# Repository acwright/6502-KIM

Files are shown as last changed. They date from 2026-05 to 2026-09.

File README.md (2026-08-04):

6502-KIM
========

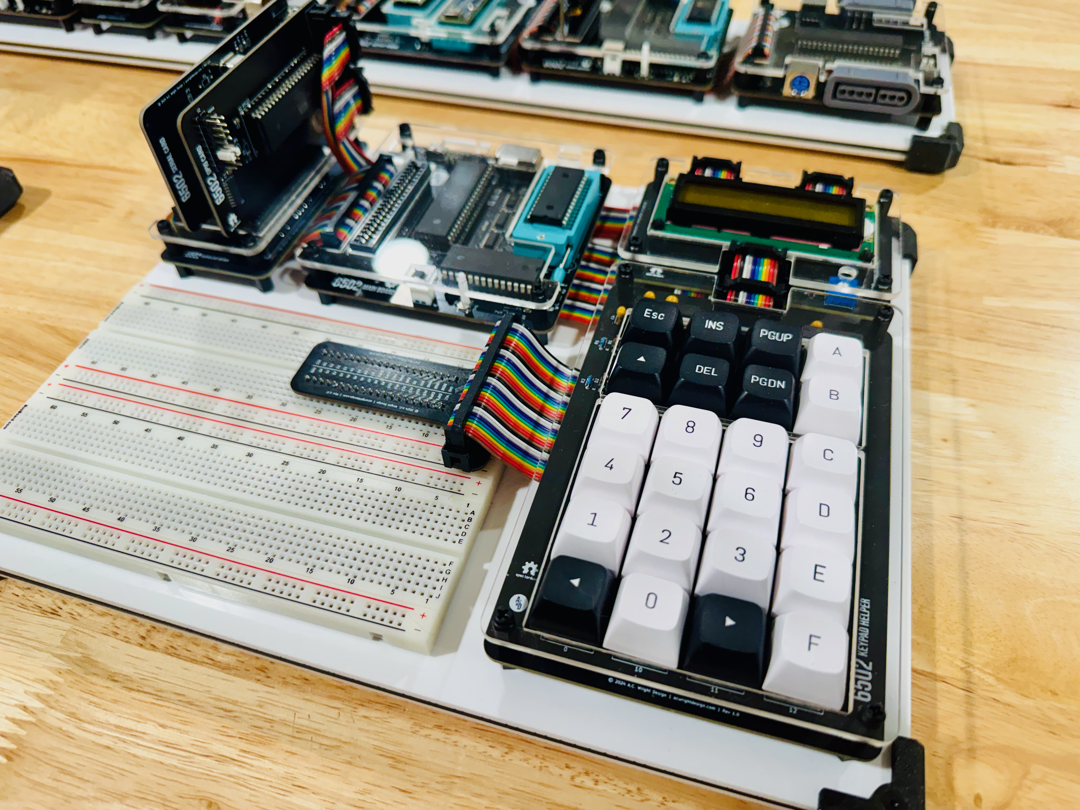
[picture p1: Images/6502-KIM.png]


*(Image shows the alternative Main Board configuration — preferred Backplane/Backplane Pro build pictured separately)*

An **AC6502** retro-style 8-bit computer based on the **65C02** microprocessor.

> 📖 **Guide:** [AC6502 Documentation](https://acwright.github.io/6502-DOCS/) — the user's and programmer's guide for the whole family.
> See [The KIM keypad add-on chapter](https://acwright.github.io/6502-DOCS/addons/kim).

---

## Table of Contents

- [Overview](#overview)
- [Architecture](#architecture)
- [Systems](#systems)
- [Software](#software)
- [Hardware](#hardware)
  - [Backplane / Backplane Pro](#backplane--backplane-pro) *(preferred)*
  - [CPU Card](#cpu-card) *(preferred)*
  - [Memory Card](#memory-card) *(preferred)*
  - [Serial Card](#serial-card)
  - [Backplane Helper](#backplane-helper)
  - [Keypad Card](#keypad-card)
  - [Keypad Helper](#keypad-helper)
  - [Keypad LCD Helper](#keypad-lcd-helper)
  - [Main Board](#main-board) *(alternative)*
- [Firmware](#firmware)
- [CAD](#cad)
- [Production](#production)
- [Schematics](#schematics)
- [Libraries](#libraries)
- [Bill of Materials](#bill-of-materials)
  - [Keypad Card](#keypad-card-1)
  - [Keypad Helper](#keypad-helper-1)
  - [Keypad LCD Helper](#keypad-lcd-helper-1)
- [Purchase](#purchase)
- [License](#license)

## Overview

The AC6502 ecosystem is a family of open-source, 65C02-based computers sharing a common architecture, memory map, and [BIOS](https://github.com/acwright/6502-BIOS). Each computer in the family is purpose-built for a different use case but runs the same software and firmware.

The **KIM** (Keypad Input Monitor) is a complete, self-contained 65C02 computer. The preferred way to build it is using a **[Backplane or Backplane Pro](https://github.com/acwright/6502-COB)**, **[CPU Card](https://github.com/acwright/6502-COB)**, and **[Memory Card](https://github.com/acwright/6502-COB)** from the COB project, along with the **[Serial Card](https://github.com/acwright/6502-COB)** and **[Backplane Helper](https://github.com/acwright/6502-COB)** (also from COB) and the **Keypad Card** — a card that the **Keypad Helper** (keypad matrix) and **Keypad LCD Helper** (16x2 LCD display) attach to. As an alternative, the **[Main Board](https://github.com/acwright/6502-VCS)** from the VCS project can be substituted for the Backplane/CPU/Memory combination.

## Architecture

All AC6502 computers share:

- **CPU**: 65C02 (or accurate emulation)
- **Memory**: 32KB RAM + 32KB ROM, with optional banked RAM expansion
- **Memory Map**: Standardized across the ecosystem — zero page, stack, I/O space ($8000–$9FFF), system ROM, and interrupt vectors at $FFFA–$FFFF
- **Bus**: 16-bit address bus, 8-bit bidirectional data bus, standard 65C02 control signals (RW, PHI2, RESET, IRQ, NMI, RDY, SYNC)
- **BIOS**: A common [BIOS](https://github.com/acwright/6502-BIOS) provides the kernel, monitor, and BASIC interpreter across all systems

## Systems

| Project | Description |
|---|---|
| [6502-ACE](https://github.com/acwright/6502-ACE) | All-in-one Computer Experience — A single board computer |
| [6502-COB](https://github.com/acwright/6502-COB) | Computer On a Backplane — Modular desktop computer with expandable card slots |
| [6502-DEV](https://github.com/acwright/6502-DEV) | Development Environment Vehicle — Emulation-based dev system |
| [6502-KIM](https://github.com/acwright/6502-KIM) | Keypad Input Monitor - KIM-1 inspired minimal computer (YOU ARE HERE) |
| [6502-VCS](https://github.com/acwright/6502-VCS) | Video Computer System — Cartridge-based retro gaming console |

## Software

| Project | Description |
|---|---|
| [6502-BIOS](https://github.com/acwright/6502-BIOS) | The shared BIOS (kernel, monitor, BASIC) for all AC6502 computers |
| [6502-EMULATOR](https://github.com/acwright/6502-EMULATOR) | Emulator for the whole family — desktop app, browser build, and a command line for scripted runs |
| [6502-PRG](https://github.com/acwright/6502-PRG) | Template project for writing assembly language programs |
| [6502-CRT](https://github.com/acwright/6502-CRT) | Template project for writing assembly language cartridges |
| [6502-ASM](https://github.com/acwright/6502-ASM) | Assembly language example programs and demos |
| [6502-BAS](https://github.com/acwright/6502-BAS) | BASIC program listings |
| [6502-WOZMON](https://github.com/acwright/6502-WOZMON) | Wozmon as a standalone ROM |
| [6502-NOP](https://github.com/acwright/6502-NOP) | An all-NOP ROM, for probing a board during bring-up |
| [6502-DOCS](https://github.com/acwright/6502-DOCS) | The documentation site — the guide, the printable reference cards, branding and label artwork |
| [cffs](https://github.com/acwright/cffs) | Builds CompactFlash disk images for the BIOS filesystem |
| [bastok](https://github.com/acwright/bastok) | Tokenizes BASIC listings into `.prg` images, and back |
| [bin2woz](https://github.com/acwright/bin2woz) | Converts a binary into a Wozmon serial upload |

## Hardware

This repository contains KiCad 7.0+ PCB designs for the KIM-specific hardware. The KIM also uses boards, cards, and helpers from the [6502-COB](https://github.com/acwright/6502-COB) project, and optionally from the [6502-VCS](https://github.com/acwright/6502-VCS) project.

### Backplane / Backplane Pro
[`Hardware/Backplane/`](https://github.com/acwright/6502-COB/tree/main/Hardware/Backplane) *(6502-COB — preferred)*

Passive backplane providing 5 card slots with full bus interconnect across all slots. The **Backplane Pro** is an enhanced variant with integrated clock generation, reset circuitry, and power distribution.

### CPU Card
[`Hardware/CPU Card/`](https://github.com/acwright/6502-COB/tree/main/Hardware/CPU%20Card) *(6502-COB — preferred)*

Hosts the 65C02 CPU in a card form factor. Plugs into the Backplane or Backplane Pro.

### Memory Card
[`Hardware/Memory Card/`](https://github.com/acwright/6502-COB/tree/main/Hardware/Memory%20Card) *(6502-COB — preferred)*

Provides 32KB SRAM and 32KB EEPROM with address decoding logic. Plugs into the Backplane or Backplane Pro.

### Serial Card
[`Hardware/Serial Card/`](https://github.com/acwright/6502-COB/tree/main/Hardware/Serial%20Card) *(6502-COB)*

RS-232 serial communication via 65C51 ACIA and MAX232 level shifter. Optional — usually fitted, and required for the KC Monitor's serial monitor, but the KIM runs keypad-only without it.

### Backplane Helper
[`Hardware/Backplane Helper/`](https://github.com/acwright/6502-COB/tree/main/Hardware/Backplane%20Helper) *(6502-COB)*

Adds additional card slots to expand the total backplane configuration.

### Main Board
[`Hardware/Main Board/`](https://github.com/acwright/6502-VCS/tree/main/Hardware/Main%20Board) *(6502-VCS — alternative)*

An all-in-one board containing the 65C02 CPU, 32KB SRAM, 32KB EEPROM, clock, and reset circuitry. Can be used in place of the Backplane + CPU Card + Memory Card combination.

### Keypad Card
`Hardware/Keypad Card/`

The card that makes the KIM a KIM. A cartridge card carrying its own ROM and I/O, which the Keypad Helper and Keypad LCD Helper attach to. Provides:

- **PIA**: 65C21 — Port A carries the keypad code (PA0–PA4) and the LCD control lines (PA5 = RS, PA6 = R/W, PA7 = E); Port B is the LCD data bus. CA1 is the keypad data-available interrupt, CA2 the keypad encoder's output enable.
- **ROM**: AT28C64 8KB EEPROM holding the cartridge firmware — see [Firmware](#firmware)
- **Decoding**: two 74HC138 decoders
- **Ports**: PORT A and PORT B headers for the keypad accessories

Unlike every other card in the family, the Keypad Card **overlays the top of the address space**. Its ROM replaces BASIC, the Monitor, Wozmon and the CPU vectors, while `$A000–$BFFF` stays reachable and is called into by the cartridge:

| Range | Contents |
|---|---|
| `$A000–$B7FF` | BIOS Kernal (unchanged, still callable) |
| `$B800–$BFFF` | CP437 character set (unchanged, still readable) |
| `$C000–$DFFF` | PIA registers (mirrored I/O window) |
| `$E000–$FFF9` | Cartridge ROM (AT28C64, 8KB) |
| `$FFFA–$FFFF` | CPU vectors (NMI, RESET, IRQ) — the cartridge's own |

This takeover is the reason the KIM behaves differently from every other system in the family, and it is why the KIM is not currently emulated by the [emulator](https://github.com/acwright/6502-EMULATOR) or the [DEV board](https://github.com/acwright/6502-DEV).

### Keypad Helper
`Hardware/Keypad Helper/`

The keypad itself, attaching to the Keypad Card — either directly to PORT A, or through the pass-through header on the Keypad LCD Helper. Provides:

- **Input**: 24 Cherry MX key switches wired as a 4×6 matrix
- **Encoder**: MM74C922 16-key encoder, extended to 24 keys with a 74HC00
- **Output**: 5-bit keycode plus a data-available strobe over a 2×6 PORT header

Scanning, debounce and encoding are all done in hardware. The helper carries no microcontroller and runs no firmware of its own.

### Keypad LCD Helper
`Hardware/Keypad LCD Helper/`

Display companion board that sits between the Keypad Card and the Keypad Helper. Provides:

- **Display**: 16×2 HD44780 LCD with a 10kΩ contrast trimmer, driven from PORT A (RS, R/W, E) and PORT B (8-bit data bus)
- **Pass-through**: a KEYPAD header carrying PA0–PA4, CA1 and CA2 straight through to the Keypad Helper

Like the Keypad Helper, this board carries no microcontroller and runs no firmware — the LCD is driven directly by the Keypad Card's PIA.

## Firmware

`Firmware/KC Monitor/`

The **KC Monitor** is a 6502 assembly language cartridge ROM for the KIM system. It burns to the Keypad Card's AT28C64 and turns the card into a KIM-1-style hex monitor: browse and edit memory and execute code from the 24-key keypad and 16×2 LCD, with a concurrent Wozmon-compatible serial monitor over the Serial Card when one is fitted. See [`Firmware/KC Monitor/README.md`](./Firmware/KC%20Monitor/README.md).

It is the only firmware in this repository — the Keypad Helper and Keypad LCD Helper are hardware-only boards and run no code.

## CAD
`CAD/`

3D-printable enclosure bases and laser-cut top panels for the KIM system.

## Production
`Production/`

JLCPCB-ready Gerber files and BOM/CPL for PCB fabrication and assembly.

## Schematics
`Schematics/`

PDF schematics for all KIM hardware.

## Libraries
`Libraries/`

Shared KiCad symbol and footprint libraries used across all AC6502 hardware projects.

## Bill of Materials

### Keypad Card

| Reference | Qty | Value | Description | LCSC | DigiKey | Mouser | Other |
|---|-----|---|---|---|---|---|---|
| C1–C4 | 4 | 100nF | SMD Capacitor 0805 | [C49678](https://www.lcsc.com/search?q=C49678) | | | |
| J2, J3 | 2 | PORT A/B | Box Header 2×6 2.54mm | | [2057-BHR-12-VUA-ND](https://www.digikey.com/en/products/filter?keywords=2057-BHR-12-VUA-ND) | | |
| U1, U2 | 2 | 74HC138 | 3-to-8 Line Decoder | [C5602](https://www.lcsc.com/search?q=C5602) | | | |
| U3 | 1 | 65C21 | Peripheral Interface Adapter | | | [955-W65C21N6TPG-14](https://www.mouser.com/ProductDetail/955-W65C21N6TPG-14) | |
| U4 | 1 | AT28C64 | 8K×8 EEPROM | | [AT28C64B-15PU-ND](https://www.digikey.com/en/products/filter?keywords=AT28C64B-15PU-ND) | [556-AT28C64B15PU](https://www.mouser.com/ProductDetail/556-AT28C64B15PU) | |

### Keypad Helper

| Reference | Qty | Value | Description | DigiKey | Mouser | Other |
|---|-----|---|---|---|---|---|
| C1, C2, C4 | 3 | 100nF | Disc Capacitor | [478-5732-ND](https://www.digikey.com/en/products/filter?keywords=478-5732-ND) | | [AMAZON](https://www.amazon.com/PANMILED-Multilayer-Monolithic-Capacitors-Assortment/dp/B0CYQ1Z4G5) |
| C3 | 1 | 1µF | Disc Capacitor | [478-7667-ND](https://www.digikey.com/en/products/filter?keywords=478-7667-ND) | | [AMAZON](https://www.amazon.com/PANMILED-Multilayer-Monolithic-Capacitors-Assortment/dp/B0CYQ1Z4G5) |
| D1, D2 | 2 | 1N914 | Small Signal Diode | [1N914FS-ND](https://www.digikey.com/en/products/filter?keywords=1N914FS-ND) | | |
| J1 | 1 | PORT | Box Header 2×6 2.54mm | [2057-BHR-12-VUA-ND](https://www.digikey.com/en/products/filter?keywords=2057-BHR-12-VUA-ND) | | [AMAZON](https://www.amazon.com/uxcell-2-54mm-2x6-Pin-Straight-Connector/dp/B07DJYVZV2) |
| R1, R2 | 2 | 100kΩ | Resistor | | | [AMAZON](https://www.amazon.com/ALLECIN-8W-Metal-Film-Resistor/dp/B0C77TM3NR) |
| SW1–SW24 | 24 | 0–23 | Cherry MX Switch 1.00u | [CH196-ND](https://www.digikey.com/en/products/filter?keywords=CH196-ND) | | [AMAZON](https://www.amazon.com/dp/B0FYR5TV3X) |
| U1 | 1 | MM74C922 | 16-Key Encoder | | | [AMAZON](https://www.amazon.com/Todiys-74C922N-MM74C922N-Encoder-MM74C922/dp/B08MCJY9LP) |
| U2 | 1 | 74HC00 | Quad 2-Input NAND Gate | [296-1563-5-ND](https://www.digikey.com/en/products/filter?keywords=296-1563-5-ND) | [595-SN74HC00N](https://www.mouser.com/ProductDetail/595-SN74HC00N) | |

### Keypad LCD Helper

| Reference | Qty | Value | Description | DigiKey | Mouser | Other |
|---|-----|---|---|---|---|---|
| J1, J2, J3 | 3 | PORT A/B/KEYPAD | Box Header 2×6 2.54mm | [2057-BHR-12-VUA-ND](https://www.digikey.com/en/products/filter?keywords=2057-BHR-12-VUA-ND) | | [AMAZON](https://www.amazon.com/uxcell-2-54mm-2x6-Pin-Straight-Connector/dp/B07DJYVZV2) |
| R1 | 1 | R | Resistor | | | |
| U2 | 1 | LCD-16X2 | 16×2 LCD Display | | | [AMAZON](https://www.amazon.com/MECCANIXITY-Display-Backlight-Interface-Adapter/dp/B0DSFXK7QK) |
| VR1 | 1 | 10kΩ | Potentiometer | [3386F-103LF-ND](https://www.digikey.com/en/products/filter?keywords=3386F-103LF-ND) | | |

## Purchase

I have a few PCBs available on Tindie for those interested in building their own AC6502 system without ordering from a fab directly.



## License

Hardware designs are released under the [CERN Open Hardware Licence Version 2 – Permissive](https://ohwr.org/cern_ohl_p_v2.txt).  
Firmware is released under the [MIT License](./Firmware/KC%20Monitor/LICENSE).

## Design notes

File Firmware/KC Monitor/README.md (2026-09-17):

KC Monitor
==========

A KIM-1-style keypad/LCD memory monitor for the **Keypad Card (KC)** of the
[AC6502 KIM](https://github.com/acwright/6502-KIM).

KC Monitor is a 6502 cartridge ROM that turns the Keypad Card into a standalone
hex monitor. You can inspect and edit memory, navigate the address space, and
execute code directly from the 24-key keypad and 16×2 LCD. A concurrent,
Wozmon-compatible serial monitor runs at the same time
over the Serial Card, so memory can also be examined, deposited, and executed
from a terminal while the keypad UI stays live. Both consoles run a program the
same way — as a subroutine — so an `RTS` comes back to the monitor whichever one
you launched from.

## Features

- **KIM-1-style keypad monitor** — navigate addresses, edit bytes one nibble at
  a time, and run code from the keypad.
- **16×2 HD44780 LCD display** — shows the current address and the byte stored
  there, plus mode/help on the second line.
- **Execute & return** — launch a program with `UP` from the pad or `XXXX R`
  from the terminal; either runs it as a subroutine, and an `RTS` returns to the
  monitor (and, from the terminal, to a fresh prompt).
- **ESC = break-to-monitor** — press `ESC` to abort a running program from
  anywhere (keypad- or serial-launched) and return to the live monitor.
- **Concurrent Wozmon serial monitor** — the Apple-1 Wozmon command set over the
  Serial Card, running alongside the keypad UI on shared memory.
- **bin2woz compatible** — stream the output of
  [bin2woz](https://github.com/acwright/bin2woz) into the serial port to "upload"
  a binary, then run it with `XXXX R`.

## Hardware

KC Monitor targets the Keypad Card, a cartridge that overlays the `$C000–$FFFF`
address space. It drives:

- A **16×2 HD44780 LCD** and a **24-key keypad** through a **65C21 PIA**.
- The **Serial Card** (R65C51 ACIA) for the concurrent serial monitor. The
  Serial Card is optional: the ACIA is only touched when the BIOS boot probe
  set `HW_SC` in `HW_PRESENT`, so a machine assembled without it comes up as a
  keypad-only monitor rather than reading a floating bus at `$9000`.

| Range | Contents |
|---|---|
| `$C000–$DFFF` | PIA registers (mirrored I/O window) |
| `$E000–$FFF9` | Cartridge ROM (AT28C64, 8 KB) |
| `$FFFA–$FFFF` | CPU vectors (NMI, RESET, IRQ) |

The PIA is mapped with A0=RS0, A1=RS1: `$C000` PORTA/DDRA, `$C001` CRA,
`$C002` PORTB/DDRB, `$C003` CRB. Port A carries the keypad code (PA0–PA4) and the
LCD control lines (PA5=RS, PA6=R/W, PA7=E); Port B is the LCD data bus. Keypad
input is interrupt driven via the 74C922 encoder's data-available signal on CA1.

### Startup

Both consoles show the same splash and both hold at the same gate:

```
KIM MONITOR v1.0
--ESC TO START--
```

`ESC` — and only `ESC` — starts the monitor, and one `ESC` starts both. Press
the keypad `ESC` key or send `$1B` from the terminal; either is caught in the
interrupt handler, so the two behave identically. Nothing else is accepted, and
nothing typed or pressed at the splash is echoed, acted on, or held over: the
gate discards the keypad mailbox and the serial receive ring on the way through.

Once the gate opens, the LCD paints the address/byte display and *then* the
serial `> ` prompt appears. The prompt is the signal that the parser is running
— it is never shown ahead of one.

### Keypad Layout

The 24 keys map to monitor functions:

| Key | Function |
|-----|---|
| `0`–`F` | Enter a hex nibble (address or data) |
| `LEFT` / `RIGHT` | Move the current address ∓1 |
| `PGUP` / `PGDN` | Move the current address ∓`$0100` |
| `INS` | Toggle insert (data-edit) mode |
| `DEL` | Write `$00` at the current address |
| `UP` | Execute code at the current address (returns on `RTS`) |
| `ESC` | Abort a running program back to the monitor |

In navigation mode, hex keys shift the current address one nibble at a time
(KIM-1 style). In `INS` mode, hex keys edit the byte at the current address.

### Serial Monitor

The serial monitor speaks the Apple-1 Wozmon command language at **19200 baud,
8-N-1**.

| Input | Action |
|---|---|
| `XXXX` | Examine the byte at address `XXXX` |
| `XXXX.YYYY` | Examine the range `XXXX` through `YYYY` |
| `XXXX: BB BB …` | Deposit bytes starting at `XXXX` |
| `XXXX R` | Run the program at `XXXX` (returns on `RTS`) |

Because the serial and keypad monitors share the same memory, a serial deposit is
visible on the LCD at the next refresh, and vice versa.

#### Two departures from original Wozmon

The syntax is Wozmon's, byte for byte; two behaviours are not.

- **The prompt is `> `**, not `\`.
- **`R` is a `JSR`, not Wozmon's `JMP (XAML)`.** The pad's `UP` key has always
  run the program under the cursor as a subroutine, so a program ending in `RTS`
  lands back in a live monitor. Serial `R` now does the same, and prints a fresh
  prompt on return. Under the original jump semantics an `RTS` left the terminal
  with no prompt and a line buffer still holding the `XXXX R` that launched the
  program, so the next line typed was appended to it and re-ran the program.
  A program that never returns is unaffected, and `ESC` still breaks out of one.

#### Pasting, and RTS/CTS flow control

A pasted program arrives faster than the monitor can swallow it, so the monitor
signals the far end with **RTS**, the same way the BIOS Kernal does: RTS goes up
at `$C0` unread bytes in the 256-byte receive ring and comes down again below
`$80`. **Set your terminal to RTS/CTS hardware flow control** and a paste of any
length arrives whole at 19200 baud; without it the monitor still never loses more
than the odd character, because a full ring now drops the incoming byte rather
than lapping its own reader.

Two consequences worth knowing, both of them the R6551's doing — TIC `00` raises
RTS *and turns the transmitter off*:

- **The monitor owns `$9002`.** Depositing a command-register value there holds
  only until the next character goes out, which puts RTS back where the ring
  says it belongs. There is no way to leave the board mute from the console.
- **The monitor goes quiet while the ring is full.** Above the high-water mark it
  drops what it was going to say rather than lowering RTS to say it, because
  every one of those windows would let the far end push more in and the ring
  would never recover. So a long paste is echoed only in part. The deposits all
  land; read them back when the paste is done.

The panel is repainted once at the end of a batch rather than once per line: a
full `RefreshDisplay` is about 22 ms of LCD time, which is more than a line of
paste takes to arrive at 19200 baud.

## Building

### Prerequisites

#### cc65 toolchain

KC Monitor is assembled with [cc65](https://github.com/cc65/cc65) (the `cl65`
driver). On macOS:

```bash
brew install cc65
```

#### Optional: minipro (for EEPROM burning)

```bash
brew install minipro
```

### Build Commands

| Command | Description |
|---|---|
| `make` | Assemble the cartridge ROM (`KC Monitor.bin`) |
| `make view` | Display a hexdump of the built ROM |
| `make eeprom` | Burn the ROM to an AT28C64 EEPROM via a TL866 programmer |
| `make clean` | Remove build artifacts |

### Build Output

```bash
make
```

Produces:

- `KC Monitor.bin` — 8 KB ROM image (`$E000–$FFFF`), ready to burn to an AT28C64.
- `KC Monitor.lst` — assembly listing file for debugging.

### Programming the EEPROM

```bash
make eeprom
```

Burns `KC Monitor.bin` to an AT28C64 EEPROM using a TL866-compatible programmer
and minipro.

## Project Structure

| File | Purpose |
|---|---|
| `KC Monitor.asm` | Firmware source — LCD driver, keypad input, monitor state machine, serial monitor, vectors |
| `kim.inc` | Machine include — the KIM as it is *with the cartridge fitted* |
| `kim.cfg` | Linker configuration — 8 KB ROM at `$E000` plus CPU vectors |
| `Makefile` | Build system |

### `kim.inc` vs the family-wide `6502.inc`

The BIOS repository ships a `6502.inc` describing the AC6502 family, and it is
the wrong file to build a KIM against. It documents a fully populated ACE with
the whole 32 KB BIOS ROM intact — banked RAM, RTC, CompactFlash, GPIO, SID,
video, BASIC, the machine code monitor and Wozmon. On a KIM none of those cards
are fitted and the top of the ROM is overlaid by this cartridge, so following
that file leads you to call routines that quietly do nothing, to enter a monitor
that is no longer there, and to reuse "spare" RAM that this firmware is
actively using.

`kim.inc` is the KIM's own machine description and is the file to include. It
states what the overlay removes, tags every Kernal entry point with what it
actually does on a KIM (`[WORKS]`, `[SERIAL]`, `[INERT]`, `[FAILS]`, `[BROKEN]`),
defines only hardware the KIM really has — the Keypad Card PIA and the Serial
Card ACIA — and marks the RAM this monitor owns:

| Region | Reserved for |
|---|---|
| `$40–$51` | Monitor and Wozmon parser state (zero page) |
| `$0200–$027F` | Wozmon line buffer — **live**, despite `6502.inc` calling this page the Kernal's input ring |
| `$0400–$04FF` | Serial RX ring, filled by the cartridge's IRQ handler |

Two consequences catch programs written against the family include: `Chrin` and
the ring routines around it always come back empty (the cartridge owns
`IRQ_PTR`, so the Kernal ring is never fed), and `Chrout` reaches the blocking
`SerialChrout`, which hangs forever if no terminal is asserting `/CTS`.

## License

See [LICENSE](LICENSE).

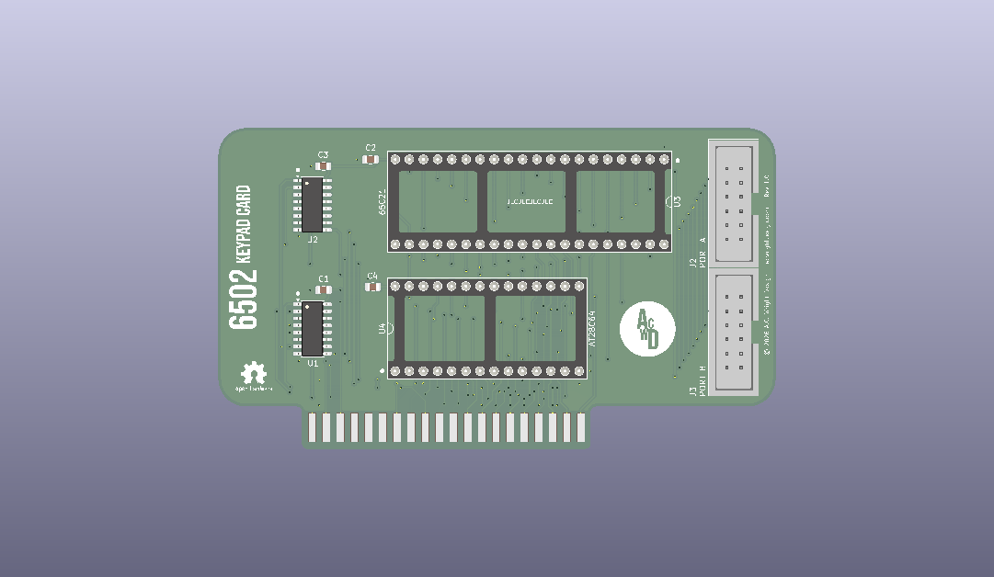
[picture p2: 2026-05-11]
CAD/Images/Keypad Card/Rev 1.0/Front.png

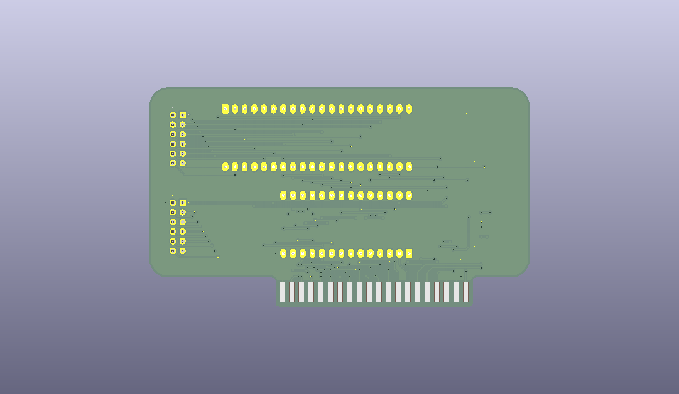
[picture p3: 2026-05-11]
CAD/Images/Keypad Card/Rev 1.0/Back.png

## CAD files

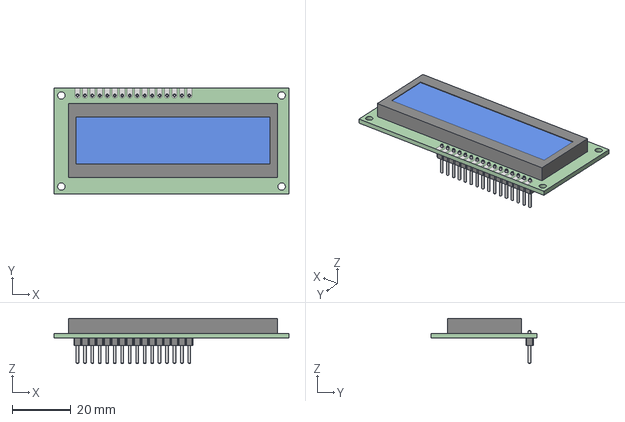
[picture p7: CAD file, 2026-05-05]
Models/LCD 16x2 HD44780 assembly.stp
80.0 x 36.0 x 15.3 mm
lcd 16_2 HD44780
dupont_pin_16

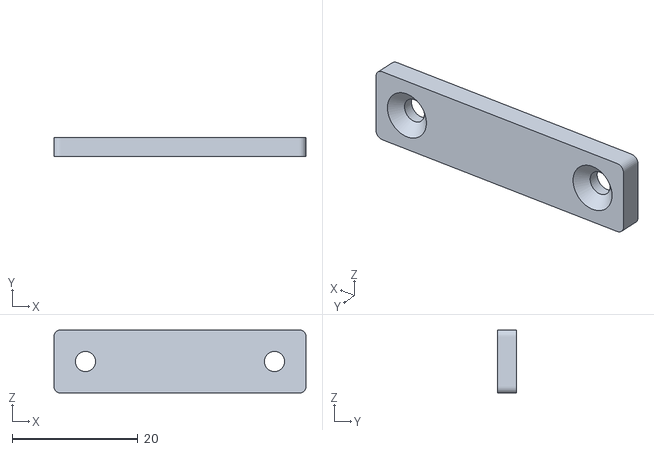
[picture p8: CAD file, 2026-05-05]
CAD/Bases/Hanger Retainer.stl
40.0 x 3.00 x 10.0

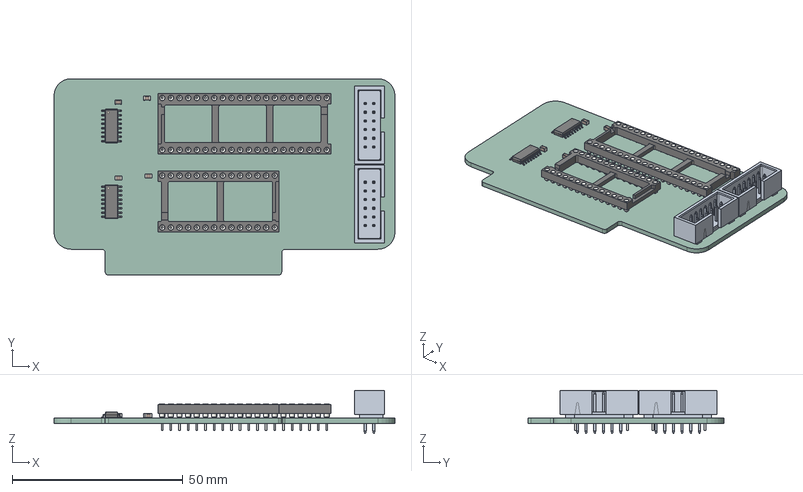
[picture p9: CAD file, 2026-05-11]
CAD/Models/Keypad Card/Rev 1.0/Keypad Card.step
100.0 x 57.6 x 12.7 mm
DIP-28_W15.24mm_Socket
DIP-40_W15.24mm_Socket
C_0805_2012Metric x 4
SOIC-16_3.9x9.9mm_P1.27mm x 2
Keypad Card_PCB

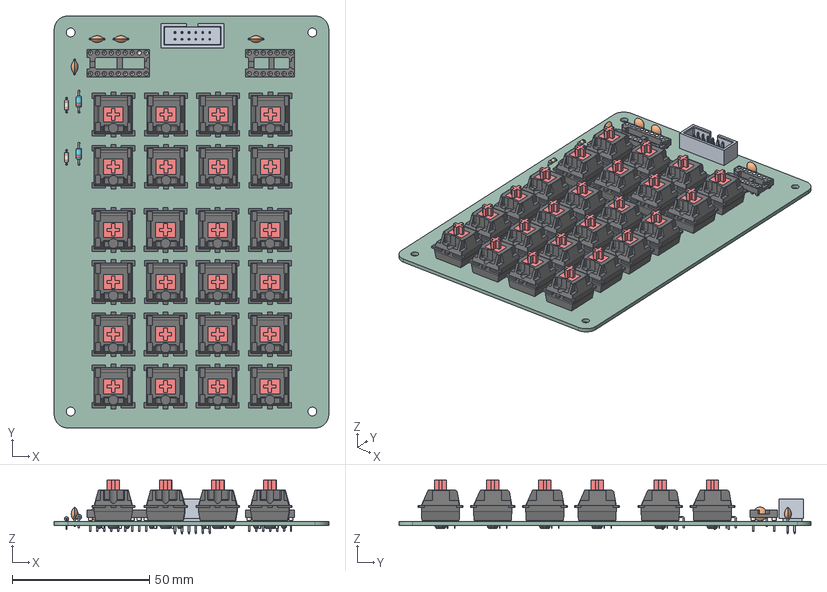
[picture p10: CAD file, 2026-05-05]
CAD/Models/Keypad Helper/Rev 1.0/Keypad Helper.step
100.0 x 150.0 x 19.6 mm
DIP-14_W7.62mm_Socket
D_DO-35_SOD27_P7.62mm_Horizontal x 2
R_Axial_DIN0204_L3.6mm_D1.6mm_P5.08mm_Horizontal x 2
C_Disc_D5.0mm_W2.5mm_P5.00mm x 4
DIP-18_W7.62mm_Socket
Keypad Helper_PCB

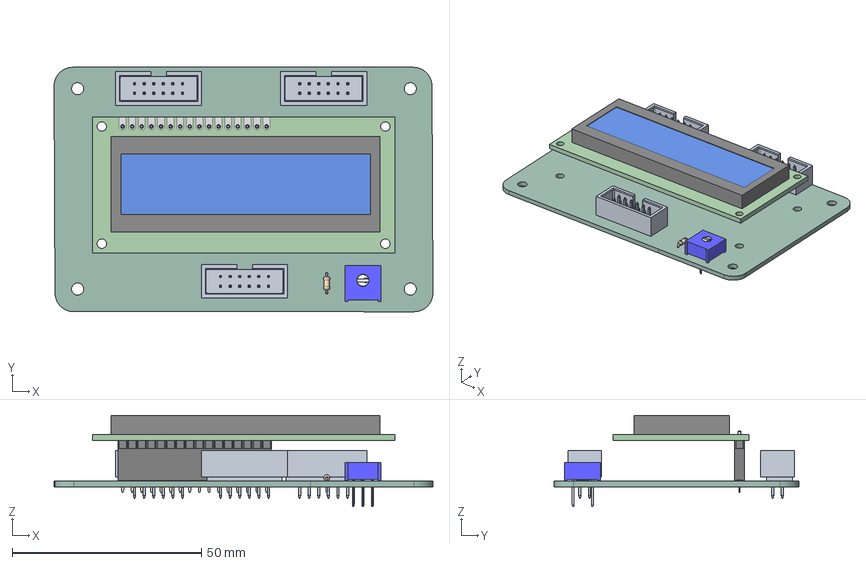
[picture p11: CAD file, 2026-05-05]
CAD/Models/Keypad LCD Helper/Rev 1.0/Keypad LCD Helper.step
100.3 x 64.7 x 24.2 mm
lcd 16_2 HD44780
dupont_pin_16
PinSocket_1x16_P2.54mm_Vertical
R_Axial_DIN0204_L3.6mm_D1.6mm_P5.08mm_Horizontal
3386F-1-103LF
Keypad LCD Helper_PCB

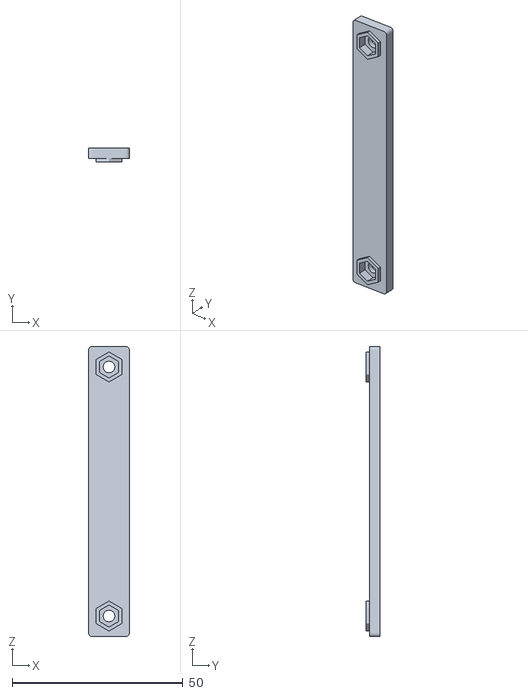
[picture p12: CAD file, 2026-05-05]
CAD/Bases/Cable Bridge Retainer.stl
12.0 x 4.00 x 85.0

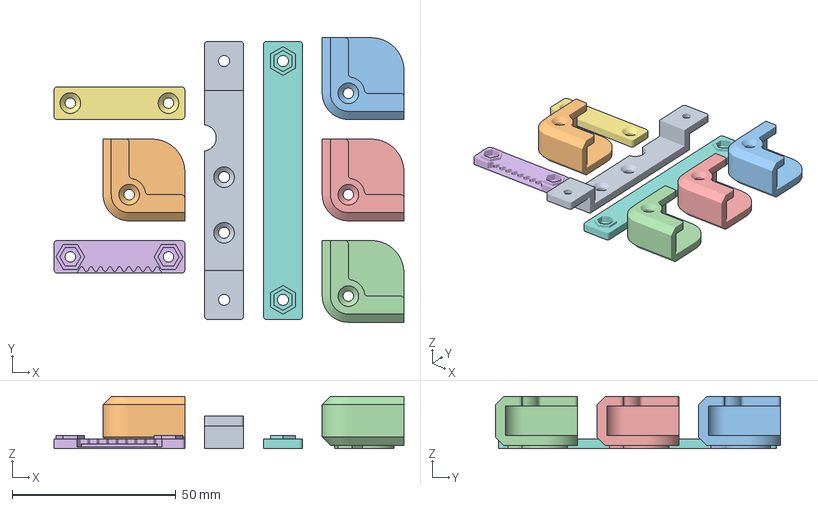
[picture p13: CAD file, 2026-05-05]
CAD/Bases/The KIM.3mf
107.0 x 87.0 x 16.0 mm
Cable Bridge.stl
Corner.stl
Hanger.stl
Hanger Retainer.stl
Cable Bridge Retainer.stl

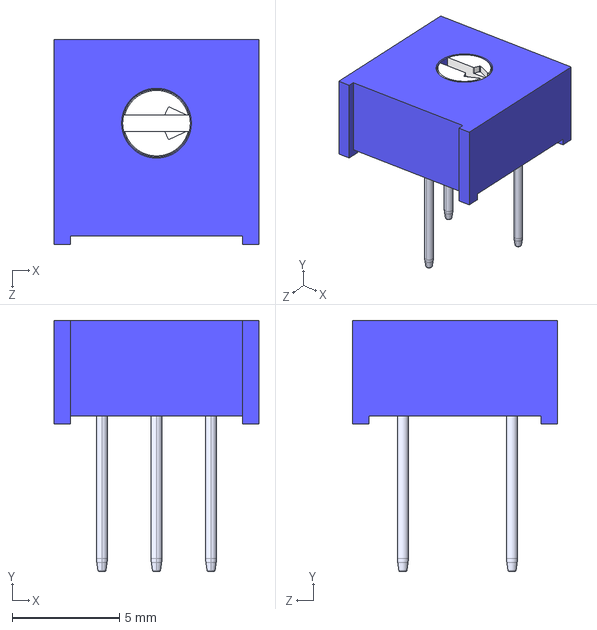
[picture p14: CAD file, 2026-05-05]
Models/3386F-1-103LF.step
9.53 x 11.7 x 9.53 mm

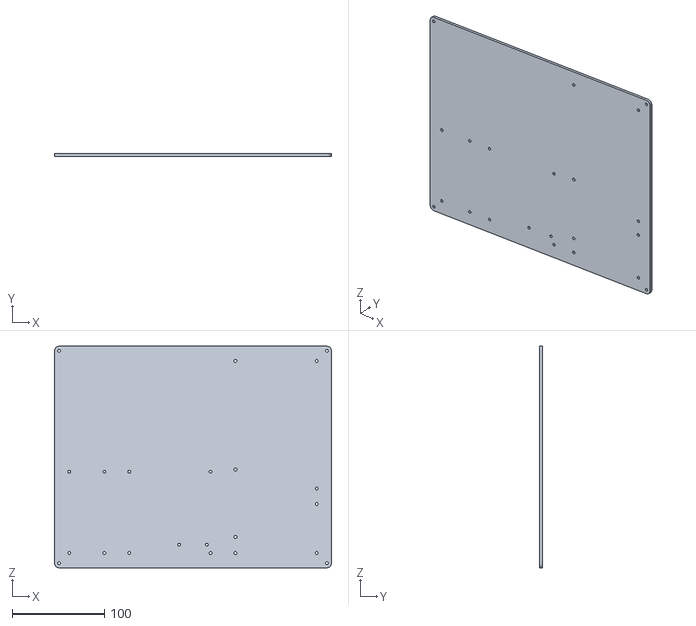
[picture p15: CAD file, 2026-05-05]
CAD/Bases/Plate.stl
300.0 x 3.00 x 240.0

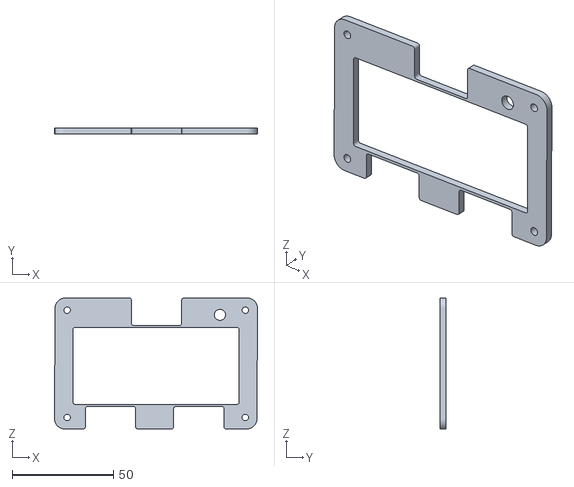
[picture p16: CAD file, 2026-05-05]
CAD/Bases/Keypad LCD Helper Top.stl
100.3 x 3.00 x 64.7

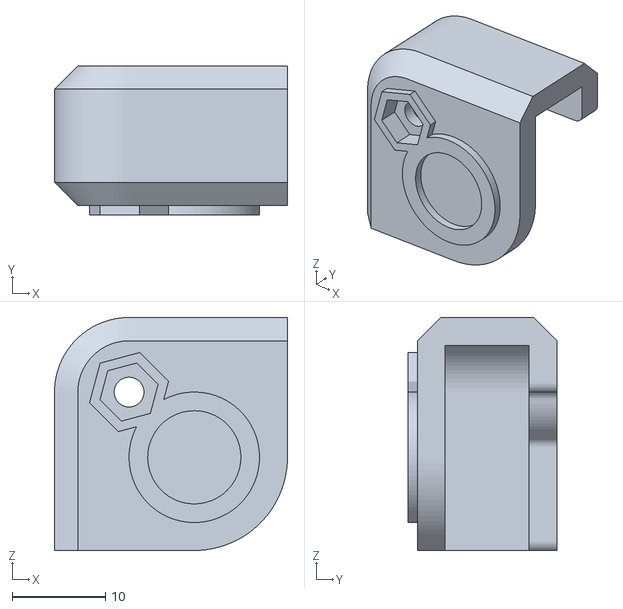
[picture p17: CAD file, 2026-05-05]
CAD/Bases/Corner.stl
25.0 x 16.0 x 25.0

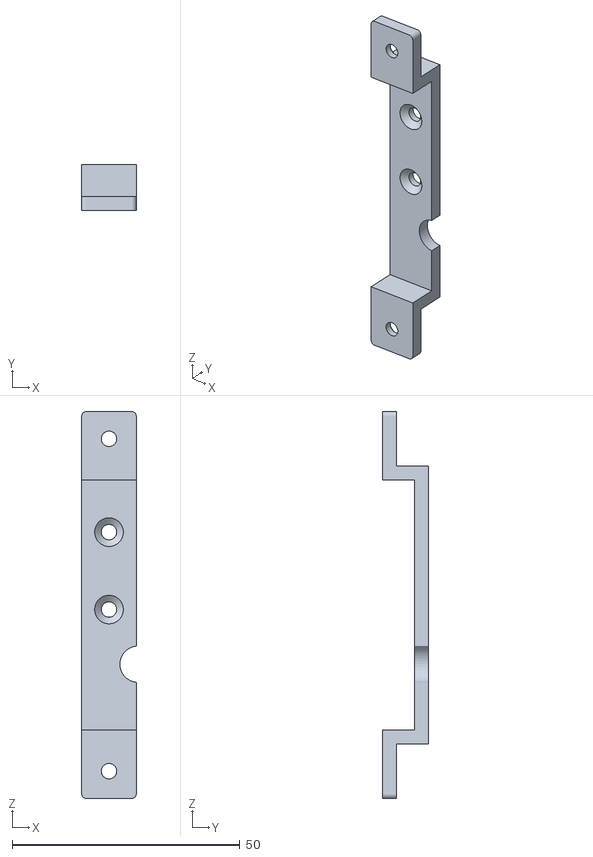
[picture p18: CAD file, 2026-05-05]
CAD/Bases/Cable Bridge.stl
12.0 x 10.0 x 85.0

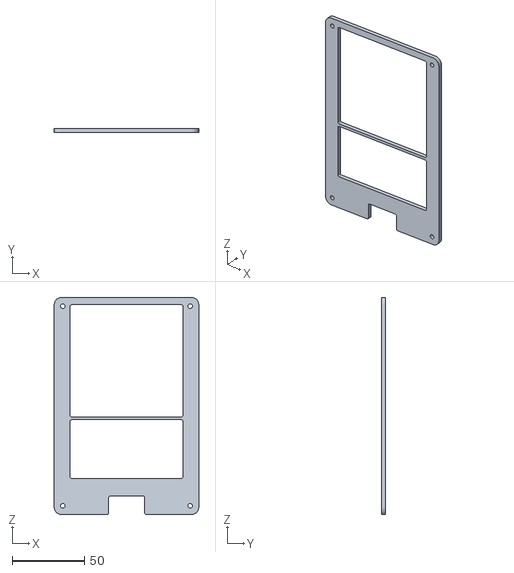
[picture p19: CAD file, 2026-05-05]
CAD/Bases/Keypad Helper Top.stl
100.0 x 3.00 x 150.0

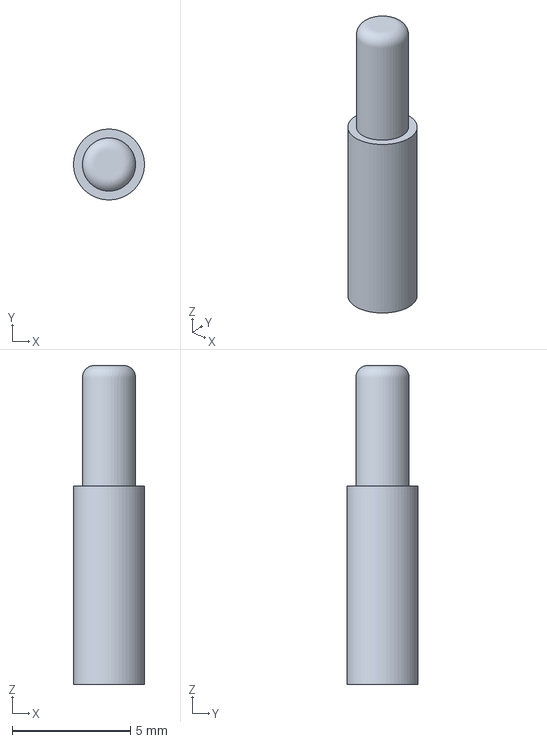
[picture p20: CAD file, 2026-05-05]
CAD/Bases/Button.3mf
3.00 x 3.00 x 13.5 mm

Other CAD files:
Models/0702461201.step
CAD/Bases/Button.stl

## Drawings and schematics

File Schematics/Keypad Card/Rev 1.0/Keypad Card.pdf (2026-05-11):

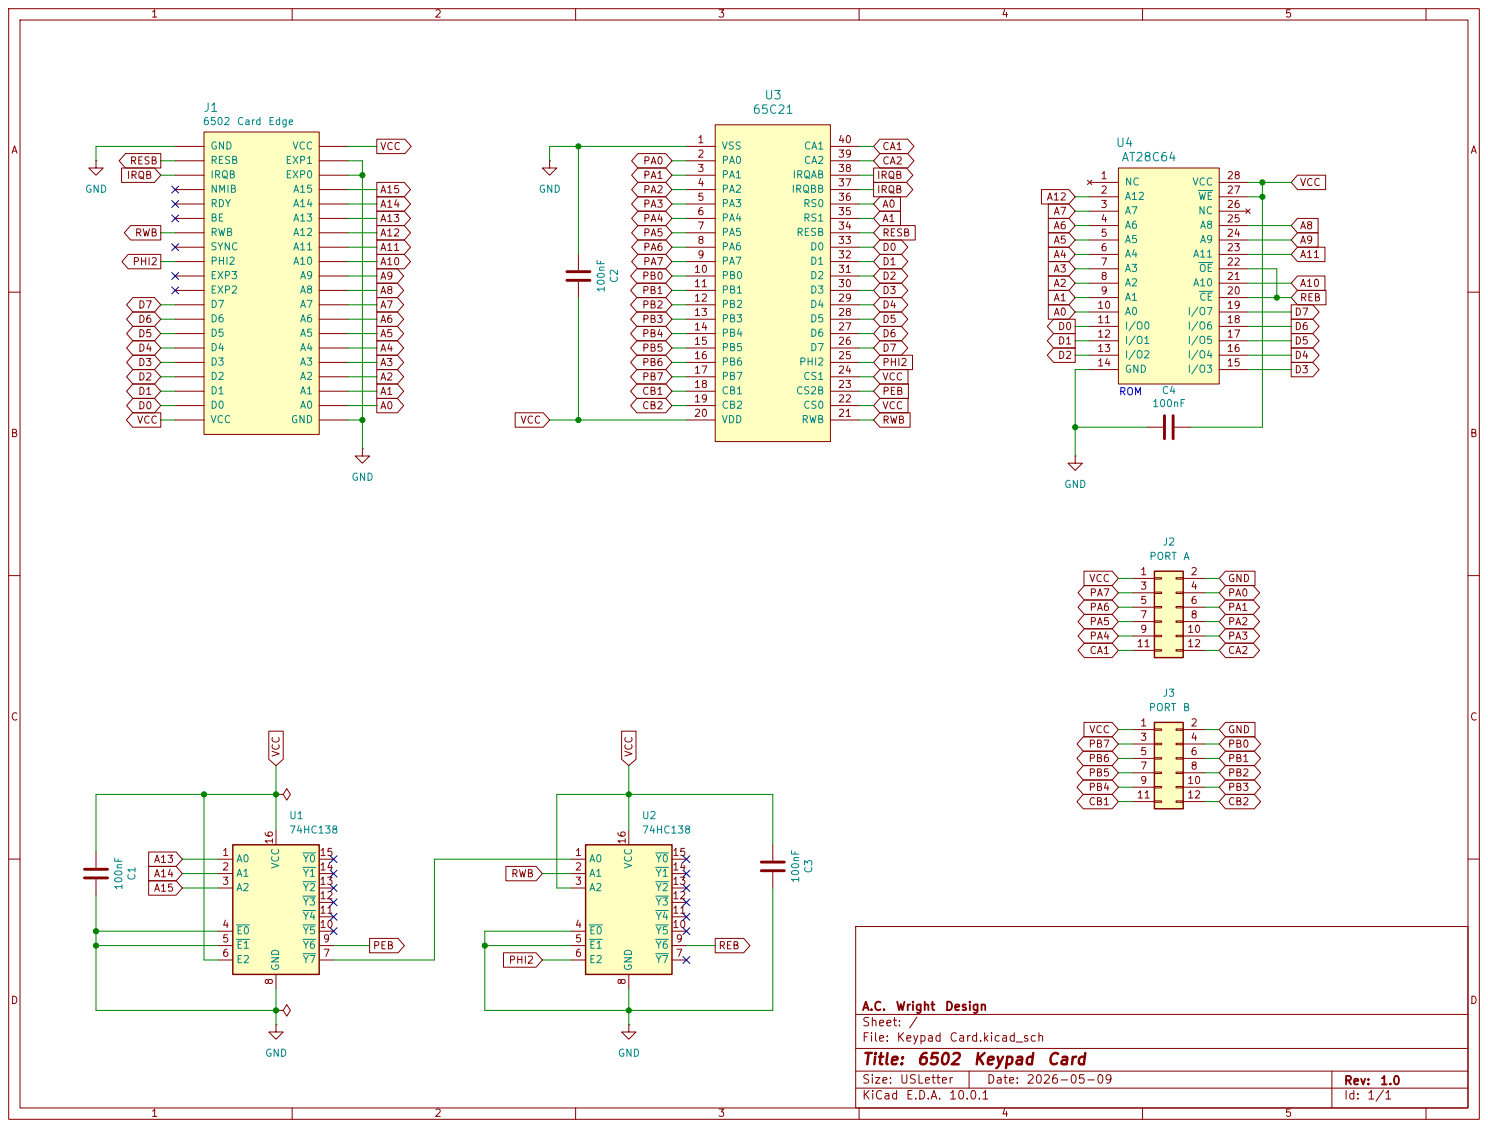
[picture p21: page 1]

Size: USLetter | Rev: 1.0
KiCad E.D.A. 10.0.1 | Id: 1/1

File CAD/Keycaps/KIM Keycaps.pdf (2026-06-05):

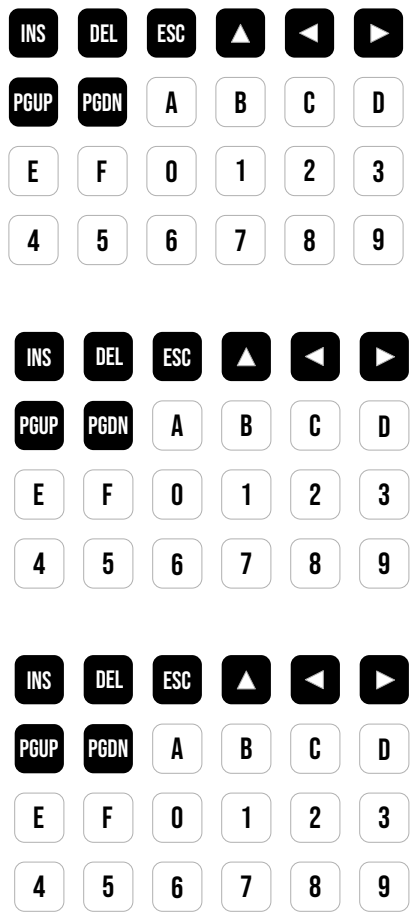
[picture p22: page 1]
PGUP PGDN; INS; DEL; ESC

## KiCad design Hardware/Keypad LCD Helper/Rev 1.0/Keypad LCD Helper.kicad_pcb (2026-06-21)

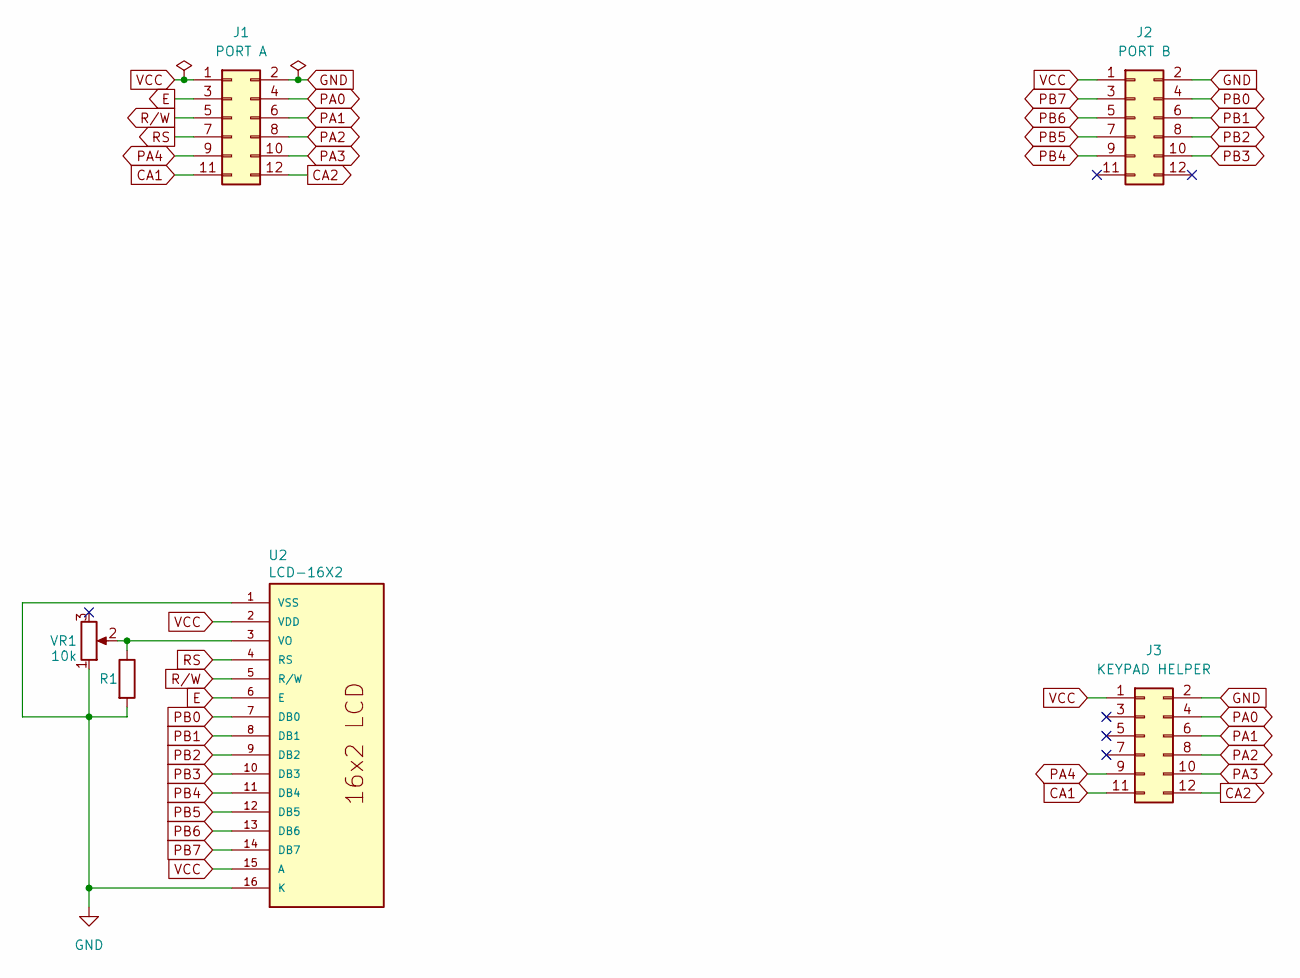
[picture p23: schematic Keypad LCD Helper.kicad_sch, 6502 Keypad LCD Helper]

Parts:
J1: PORT A; 6502 GPIO Connector; Digikey 2057-BHR-12-VUA-ND
J2: PORT B; 6502 GPIO Connector; Digikey 2057-BHR-12-VUA-ND
J3: KEYPAD HELPER; 6502 GPIO Connector; Digikey 2057-BHR-12-VUA-ND
R1: R; R_Axial_DIN0204_L3.6mm_D1.6mm_P5.08mm_Horizontal
U2: LCD-16X2
VR1: 10k; 3386F-1-103LF; Digikey 3386F-103LF-ND

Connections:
CA1: J1.11, J3.11
CA2: J1.12, J3.12
E: J1.3, U2.6 (E)
GND: J1.2, J2.2, J3.2, R1.2, U2.1 (VSS), U2.16 (K), VR1.1
unnamed: R1.1, U2.3 (VO), VR1.2
PA0: J1.4, J3.4
PA1: J1.6, J3.6
PA2: J1.8, J3.8
PA3: J1.10, J3.10
PA4: J1.9, J3.9
PB0: J2.4, U2.7 (DB0)
PB1: J2.6, U2.8 (DB1)
PB2: J2.8, U2.9 (DB2)
PB3: J2.10, U2.10 (DB3)
PB4: J2.9, U2.11 (DB4)
PB5: J2.7, U2.12 (DB5)
PB6: J2.5, U2.13 (DB6)
PB7: J2.3, U2.14 (DB7)
RS: J1.7, U2.4 (RS)
R/W: J1.5, U2.5 (R/W)
VCC: J1.1, J2.1, J3.1, U2.2 (VDD), U2.15 (A)

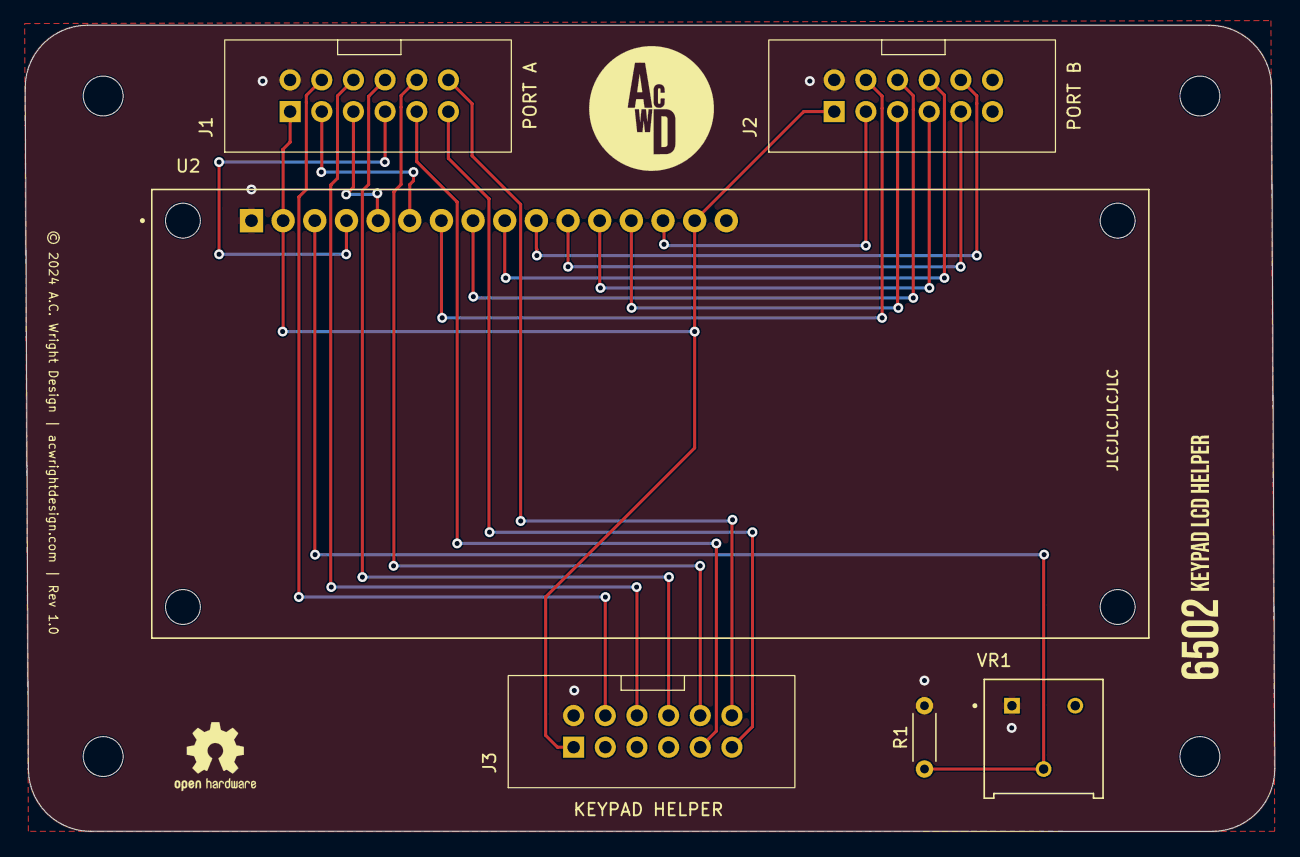
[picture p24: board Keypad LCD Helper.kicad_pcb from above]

Board: 2 copper layers, 100.3 x 64.7 mm, 10 parts (0 on the bottom side), 21 nets.

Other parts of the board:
H1, H2, H3, H4: MountingHole; MountingHole_3.2mm_M3

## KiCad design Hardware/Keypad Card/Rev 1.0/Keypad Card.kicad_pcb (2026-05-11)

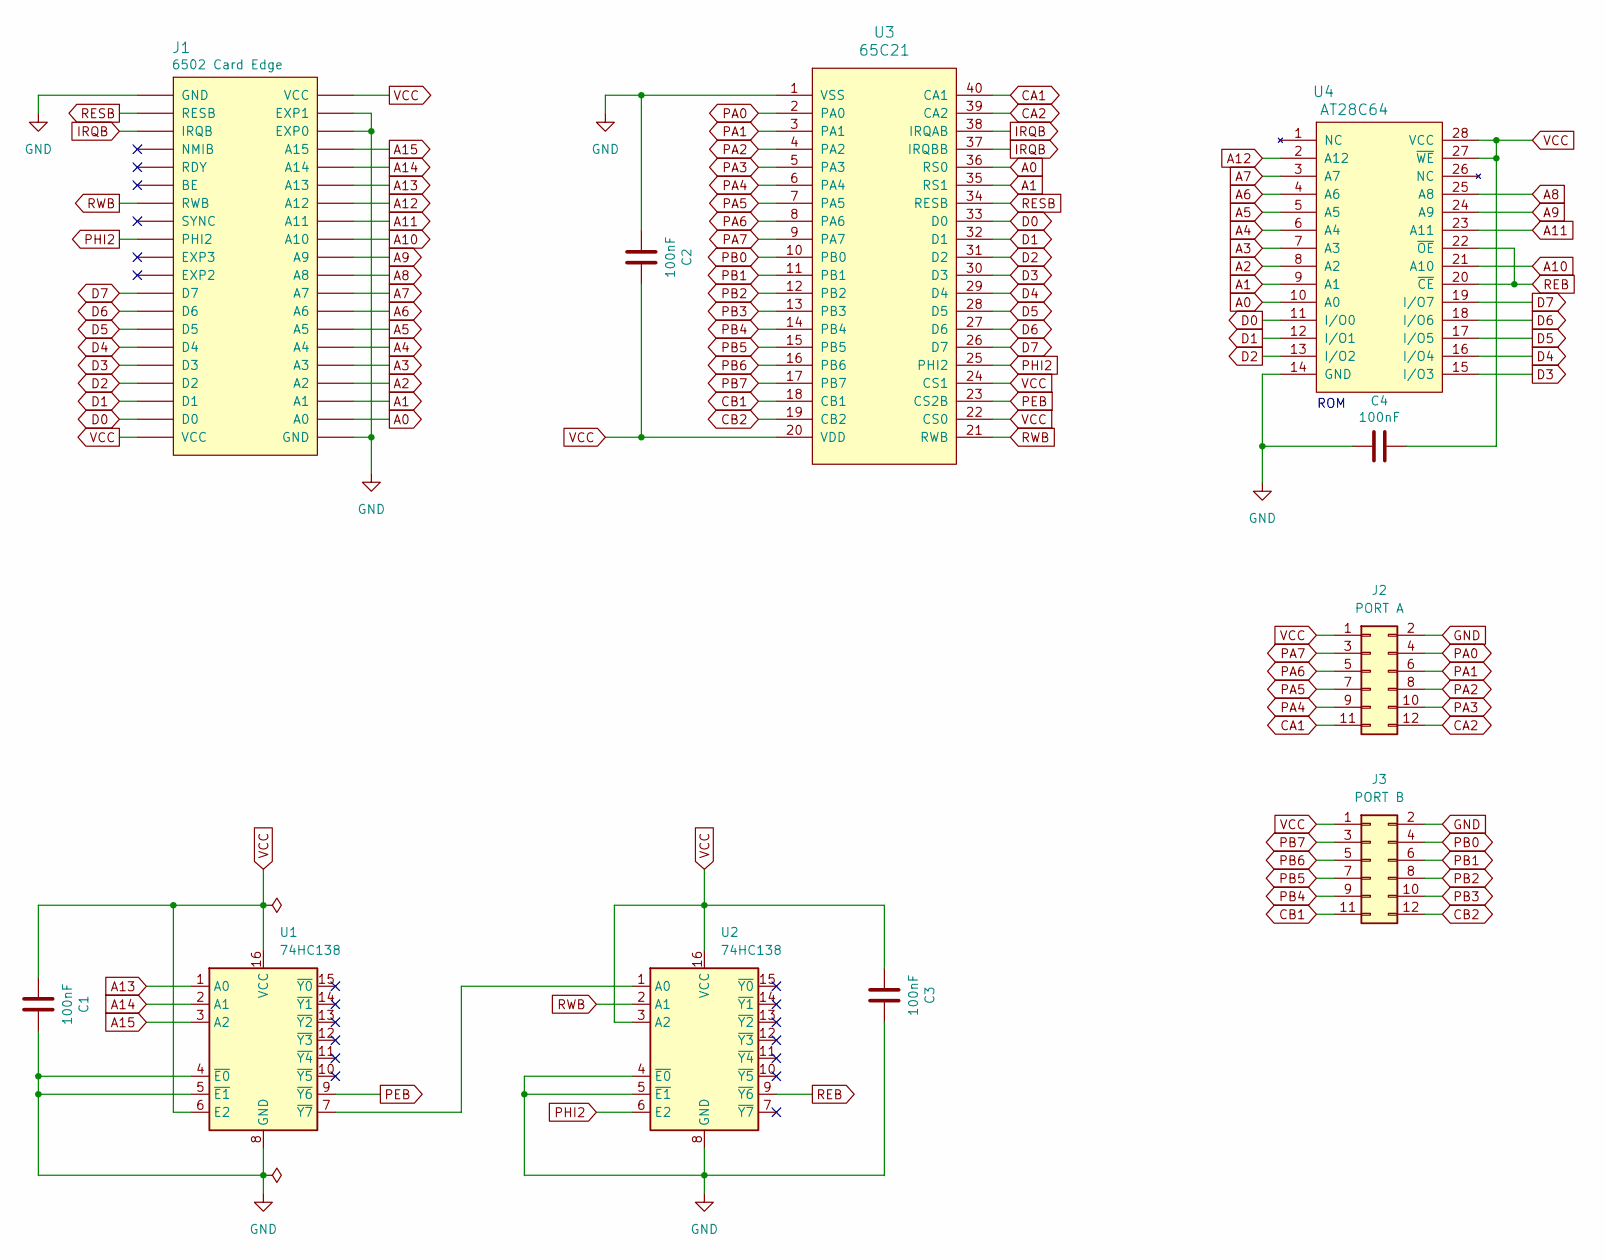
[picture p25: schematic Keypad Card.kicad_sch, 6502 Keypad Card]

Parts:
C1, C2, C3, C4: 100nF; C_0805_2012Metric; LCSC C49678
J1: 6502 Card Edge
J2: PORT A; 6502 GPIO Connector
J3: PORT B; 6502 GPIO Connector
U1, U2: 74HC138; SOIC-16_3.9x9.9mm_P1.27mm; LCSC C5602
U3: 65C21; DIP-40_W15.24mm_Socket_LongPads
U4: AT28C64; DIP-28_W15.24mm_Socket_LongPads

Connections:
A0: J1.A0, U3.36 (RS0), U4.10 (A0)
A1: J1.A1, U3.35 (RS1), U4.9 (A1)
A2: J1.A2, U4.8 (A2)
A3: J1.A3, U4.7 (A3)
A4: J1.A4, U4.6 (A4)
A5: J1.A5, U4.5 (A5)
A6: J1.A6, U4.4 (A6)
A7: J1.A7, U4.3 (A7)
A8: J1.A8, U4.25 (A8)
A9: J1.A9, U4.24 (A9)
A10: J1.A10, U4.21 (A10)
A11: J1.A11, U4.23 (A11)
A12: J1.A12, U4.2 (A12)
A13: J1.A13, U1.1 (A0)
A14: J1.A14, U1.2 (A1)
A15: J1.A15, U1.3 (A2)
CA1: J2.11, U3.40 (CA1)
CA2: J2.12, U3.39 (CA2)
CB1: J3.11, U3.18 (CB1)
CB2: J3.12, U3.19 (CB2)
D0: J1.D0, U3.33 (D0), U4.11 (I/O0)
D1: J1.D1, U3.32 (D1), U4.12 (I/O1)
D2: J1.D2, U3.31 (D2), U4.13 (I/O2)
D3: J1.D3, U3.30 (D3), U4.15 (I/O3)
D4: J1.D4, U3.29 (D4), U4.16 (I/O4)
D5: J1.D5, U3.28 (D5), U4.17 (I/O5)
D6: J1.D6, U3.27 (D6), U4.18 (I/O6)
D7: J1.D7, U3.26 (D7), U4.19 (I/O7)
GND: C1.2, C2.1, C3.2, C4.2, J1.EXP0, J1.EXP1, J1.GND, J2.2, J3.2, U1.4 (~E0), U1.5 (~E1), U1.8 (GND), U2.4 (~E0), U2.5 (~E1), U2.8 (GND), U3.1 (VSS), U4.14 (GND)
IRQB: J1.IRQB, U3.37 (IRQBB), U3.38 (IRQAB)
unnamed: U1.7 (~Y7), U2.1 (A0)
PA0: J2.4, U3.2 (PA0)
PA1: J2.6, U3.3 (PA1)
PA2: J2.8, U3.4 (PA2)
PA3: J2.10, U3.5 (PA3)
PA4: J2.9, U3.6 (PA4)
PA5: J2.7, U3.7 (PA5)
PA6: J2.5, U3.8 (PA6)
PA7: J2.3, U3.9 (PA7)
PB0: J3.4, U3.10 (PB0)
PB1: J3.6, U3.11 (PB1)
PB2: J3.8, U3.12 (PB2)
PB3: J3.10, U3.13 (PB3)
PB4: J3.9, U3.14 (PB4)
PB5: J3.7, U3.15 (PB5)
PB6: J3.5, U3.16 (PB6)
PB7: J3.3, U3.17 (PB7)
PEB: U1.9 (~Y6), U3.23 (CS2B)
PHI2: J1.PHI2, U2.6 (E2), U3.25 (PHI2)
REB: U2.9 (~Y6), U4.20 (~CE), U4.22 (~OE)
RESB: J1.RESB, U3.34 (RESB)
RWB: J1.RWB, U2.2 (A1), U3.21 (RWB)
VCC: C1.1, C2.2, C3.1, C4.1, J1.VCC, J2.1, J3.1, U1.6 (E2), U1.16 (VCC), U2.3 (A2), U2.16 (VCC), U3.20 (VDD), U3.22 (CS0), U3.24 (CS1), U4.27 (~WE), U4.28 (VCC)

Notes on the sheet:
ROM

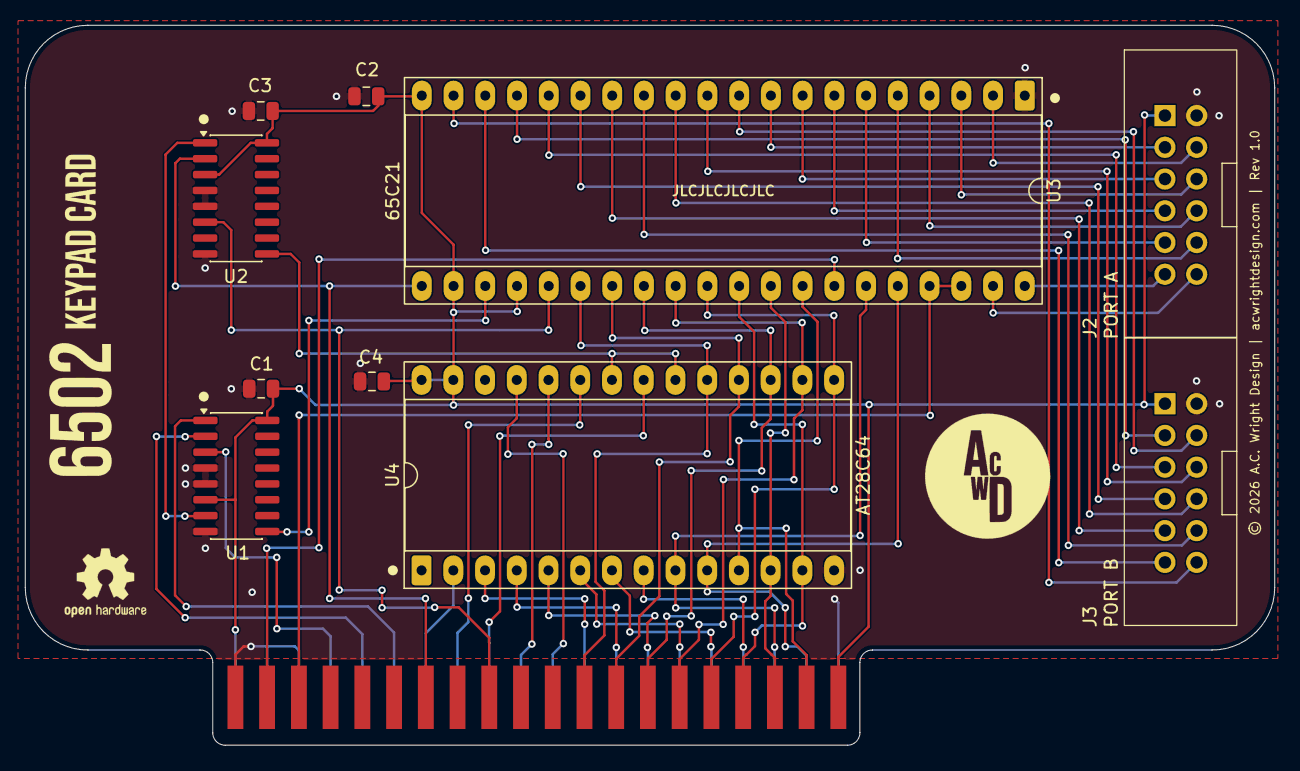
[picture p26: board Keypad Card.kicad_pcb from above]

Board: 2 copper layers, 100.0 x 57.6 mm, 11 parts (0 on the bottom side), 53 nets.

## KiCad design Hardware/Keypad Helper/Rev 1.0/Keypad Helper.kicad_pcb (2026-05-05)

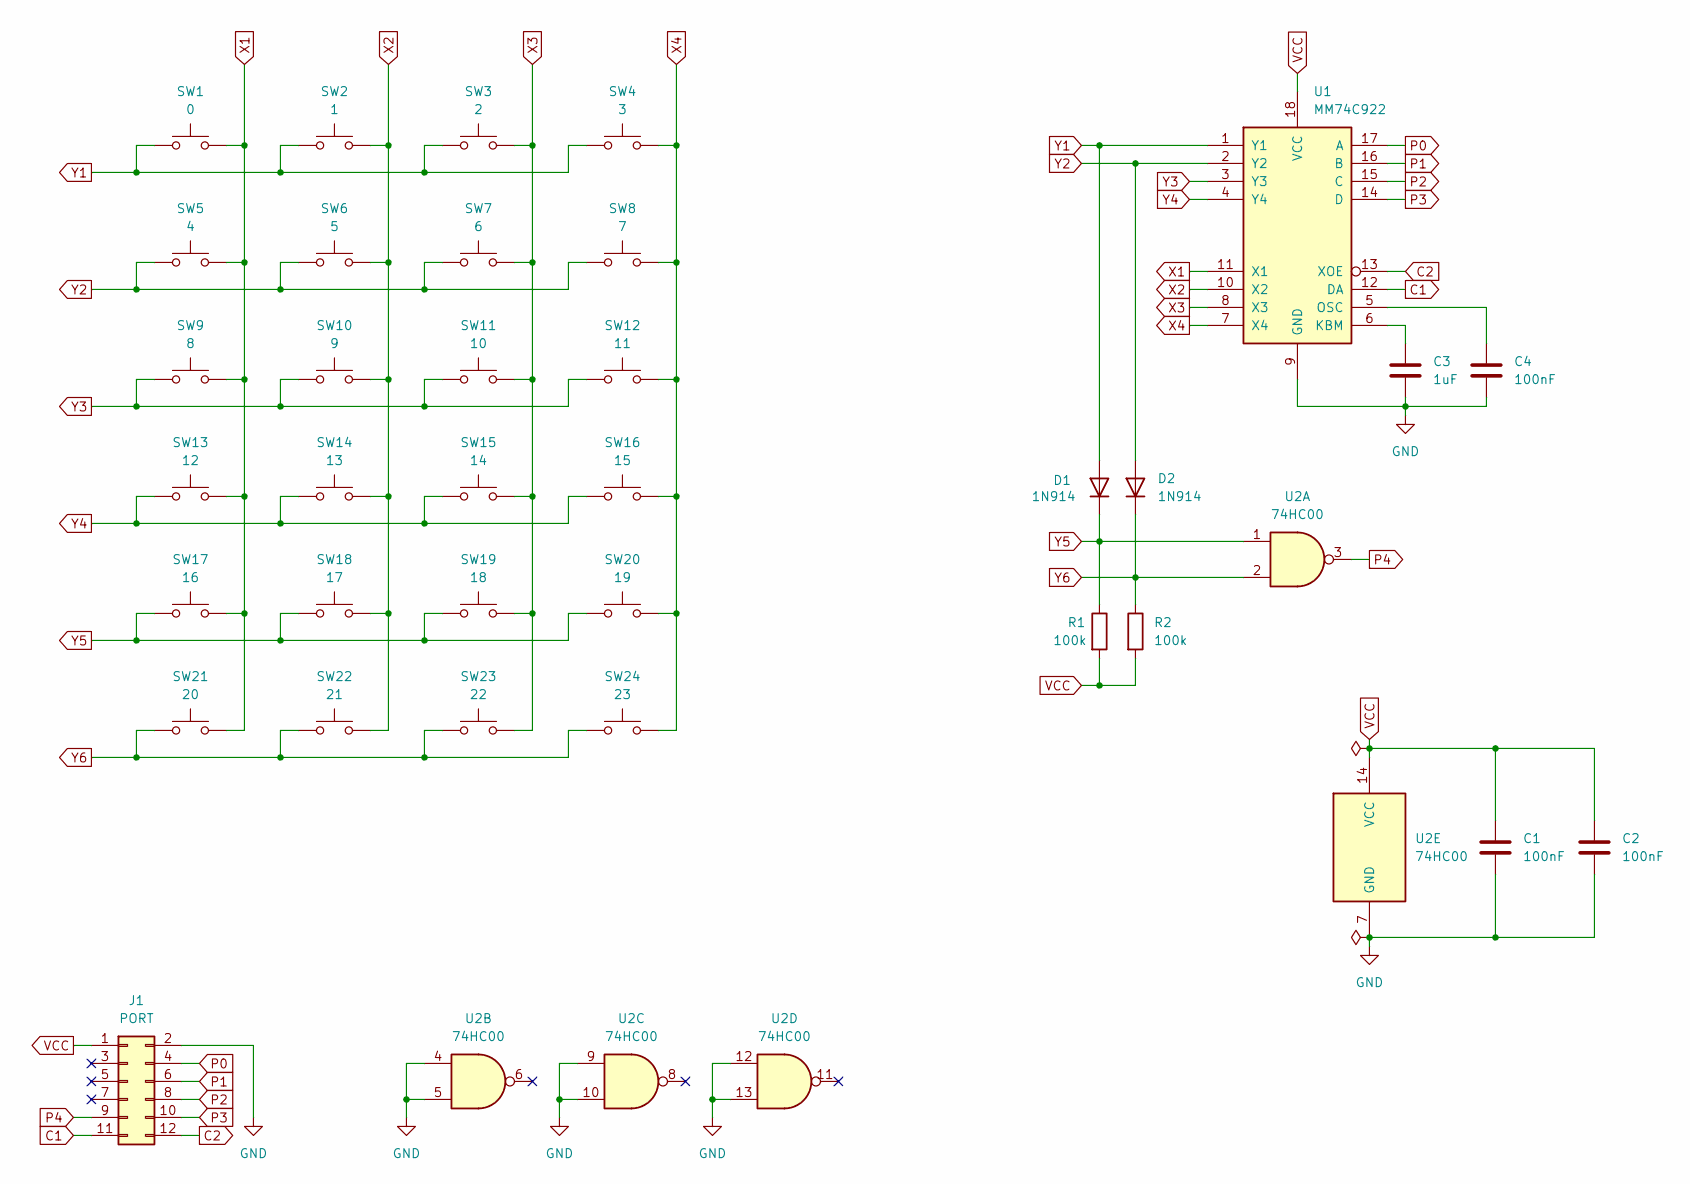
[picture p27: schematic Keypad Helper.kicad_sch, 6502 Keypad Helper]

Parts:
C1, C2, C4: 100nF; C_Disc_D5.0mm_W2.5mm_P5.00mm
C3: 1uF; C_Disc_D5.0mm_W2.5mm_P5.00mm
D1, D2: 1N914; D_DO-35_SOD27_P7.62mm_Horizontal
J1: PORT; 6502 GPIO Connector
R1, R2: 100k; R_Axial_DIN0204_L3.6mm_D1.6mm_P5.08mm_Horizontal
SW1: 0; SW_Cherry_MX_1.00u_PCB
SW2: 1; SW_Cherry_MX_1.00u_PCB
SW3: 2; SW_Cherry_MX_1.00u_PCB
SW4: 3; SW_Cherry_MX_1.00u_PCB
SW5: 4; SW_Cherry_MX_1.00u_PCB
SW6: 5; SW_Cherry_MX_1.00u_PCB
SW7: 6; SW_Cherry_MX_1.00u_PCB
SW8: 7; SW_Cherry_MX_1.00u_PCB
SW9: 8; SW_Cherry_MX_1.00u_PCB
SW10: 9; SW_Cherry_MX_1.00u_PCB
SW11: 10; SW_Cherry_MX_1.00u_PCB
SW12: 11; SW_Cherry_MX_1.00u_PCB
SW13: 12; SW_Cherry_MX_1.00u_PCB
SW14: 13; SW_Cherry_MX_1.00u_PCB
SW15: 14; SW_Cherry_MX_1.00u_PCB
SW16: 15; SW_Cherry_MX_1.00u_PCB
SW17: 16; SW_Cherry_MX_1.00u_PCB
SW18: 17; SW_Cherry_MX_1.00u_PCB
SW19: 18; SW_Cherry_MX_1.00u_PCB
SW20: 19; SW_Cherry_MX_1.00u_PCB
SW21: 20; SW_Cherry_MX_1.00u_PCB
SW22: 21; SW_Cherry_MX_1.00u_PCB
SW23: 22; SW_Cherry_MX_1.00u_PCB
SW24: 23; SW_Cherry_MX_1.00u_PCB
U1: MM74C922; DIP-18_W7.62mm_Socket_LongPads
U2: 74HC00; DIP-14_W7.62mm_Socket_LongPads

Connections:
C1: J1.11, U1.12 (DA)
C2: J1.12, U1.13 (XOE)
GND: C1.2, C2.2, C3.2, C4.2, J1.2, U1.9 (GND), U2.4, U2.5, U2.7 (GND), U2.9, U2.10, U2.12, U2.13
unnamed: C3.1, U1.6 (KBM)
unnamed: C4.1, U1.5 (OSC)
P0: J1.4, U1.17 (A)
P1: J1.6, U1.16 (B)
P2: J1.8, U1.15 (C)
P3: J1.10, U1.14 (D)
P4: J1.9, U2.3
VCC: C1.1, C2.1, J1.1, R1.2, R2.2, U1.18 (VCC), U2.14 (VCC)
X1: SW1.2, SW5.2, SW9.2, SW13.2, SW17.2, SW21.2, U1.11 (X1)
X2: SW2.2, SW6.2, SW10.2, SW14.2, SW18.2, SW22.2, U1.10 (X2)
X3: SW3.2, SW7.2, SW11.2, SW15.2, SW19.2, SW23.2, U1.8 (X3)
X4: SW4.2, SW8.2, SW12.2, SW16.2, SW20.2, SW24.2, U1.7 (X4)
Y1: D1.2 (A), SW1.1, SW2.1, SW3.1, SW4.1, U1.1 (Y1)
Y2: D2.2 (A), SW5.1, SW6.1, SW7.1, SW8.1, U1.2 (Y2)
Y3: SW9.1, SW10.1, SW11.1, SW12.1, U1.3 (Y3)
Y4: SW13.1, SW14.1, SW15.1, SW16.1, U1.4 (Y4)
Y5: D1.1 (K), R1.1, SW17.1, SW18.1, SW19.1, SW20.1, U2.1
Y6: D2.1 (K), R2.1, SW21.1, SW22.1, SW23.1, SW24.1, U2.2

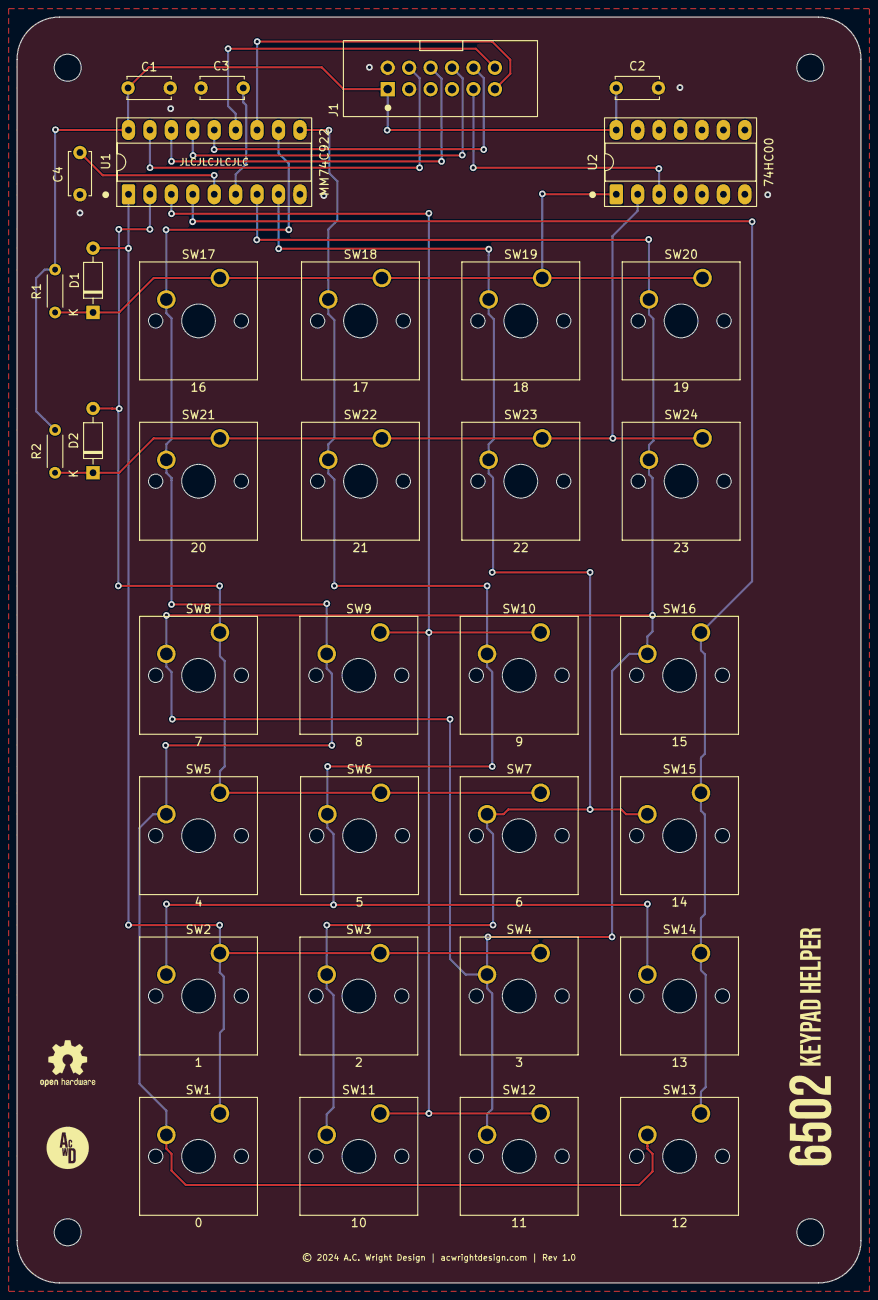
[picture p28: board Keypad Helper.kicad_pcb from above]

Board: 2 copper layers, 100.0 x 150.0 mm, 39 parts (0 on the bottom side), 21 nets.

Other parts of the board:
H1, H2, H3, H4: MountingHole; MountingHole_3.2mm_M3

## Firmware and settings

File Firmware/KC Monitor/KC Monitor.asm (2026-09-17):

.setcpu "65C02"

.include "kim.inc"

; =============================================================================
;   KC Monitor — KIM-1-style keypad/LCD memory monitor
; =============================================================================
;   Cartridge ROM for the Keypad Card (KC).  Drives a 16x2 HD44780 LCD and a
;   24-key keypad through a 65C21 PIA.  The cart overlays $C000-$FFFF; ROM
;   (AT28C64, 8 KB) lives at $E000-$FFFF and the PIA registers are mirrored
;   across the I/O window $C000-$DFFF.
;
;   The machine itself — PIA, LCD wiring, keypad codes, the surviving Kernal —
;   is described in kim.inc.  This file implements:
;     - Monitor state & build scaffolding
;     - LCD driver
;     - PIA init & keypad input
;     - Monitor state machine
;     - Entry point, interrupt handlers & CPU vectors
;     - ESC = break-to-monitor abort (handled in KeyIrq)
;     - Wozmon-compatible serial monitor (concurrent with the keypad)
; =============================================================================


; =============================================================================
;   Machine definitions
; =============================================================================
;   kim.inc describes the KIM as it actually is with this cartridge fitted:
;   the Keypad Card PIA ($C000-$C003) and its LCD/keypad wiring, the Serial
;   Card ACIA ($9000-$9003), the part of the BIOS Kernal that survives the
;   $C000-$FFFF overlay, and the RAM this monitor reserves.  Everything the
;   overlay removes — BASIC, the BIOS Monitor, Wozmon, the BIOS vectors — is
;   listed there as gone rather than silently omitted.
;
;   PORTA/CRA/PORTB/CRB, CR_DDR/CR_PORT, LCD_*, PIA_*, KEY_* and the ASCII
;   constants below all come from it.


; =============================================================================
;   Monitor zero-page state
; =============================================================================
;   Lives in the free user zero page; kim.inc reserves $40-$51 (KC_ZP_START..
;   KC_ZP_END) for the monitor so a program written for the KIM knows to keep
;   off it.  CUR_ADDR is the address the monitor is inspecting/editing; it
;   doubles as the (zp),y pointer for byte access and as the execute
;   trampoline target.  MODE holds the INS edit flag; MON_TMP is scratch for
;   the nibble-shift edits.
CUR_ADDR            := $40               ; 2 bytes — current address pointer
MODE                := $42               ; 1 byte  — INS edit-mode flag (0=off)
MON_TMP             := $43               ; 1 byte  — scratch for nibble edits
KEY_CODE            := $44               ; 1 byte  — last keycode latched by KeyIrq
KEY_READY           := $45               ; 1 byte  — nonzero when a key is pending

MODE_INS            = $01                ; MODE value: insert/edit mode active


; =============================================================================
;   Serial Wozmon zero-page state
; =============================================================================
;   A Wozmon-compatible serial monitor runs concurrently with the keypad
;   monitor, sharing the same memory.  Incoming bytes are pushed into a
;   256-byte RX ring by the IRQ handler and drained by the cooperative main
;   loop into a Wozmon line parser.  The parser variables mirror the original
;   Apple-1 Wozmon (XAML/XAMH, STL/STH, L/H, YSAV, MODE) but live in the free
;   user zero page since $24-$2B are reserved by the Kernal here.  WMODE is
;   kept distinct from the keypad MODE byte.
SER_RXHEAD          := $46               ; 1 byte  — RX ring write index (IRQ)
SER_RXTAIL          := $47               ; 1 byte  — RX ring read index (main loop)
XAML                := $48               ; 2 bytes — last "examined" address (lo/hi)
XAMH                := $49
STL                 := $4A               ; 2 bytes — current deposit address (lo/hi)
STH                 := $4B
L                   := $4C               ; 2 bytes — hex accumulator (lo/hi)
H                   := $4D
YSAV                := $4E               ; 1 byte  — saved index (hex-present test)
WMODE               := $4F               ; 1 byte  — Wozmon mode ($00=XAM, $74=STOR, $AE=BLOCK)
SER_IDX             := $50               ; 1 byte  — current line-buffer index
SER_DIRTY           := $51               ; 1 byte  — nonzero when a serial deposit changed memory

; The RX ring buffer (256 bytes, byte indices wrap naturally) and the Wozmon
; line buffer share the low-RAM input region; neither is used by the keypad
; monitor.  The line buffer is aliased onto the Kernal's input ring page,
; which is inert here (nothing feeds it once the cart owns IRQ_PTR) — kim.inc
; documents both pages as live so they are not mistaken for spare RAM.
SER_RXBUF           := KC_RXBUF          ; $0400 — 256-byte serial RX ring buffer
SER_LINEBUF         := KC_LINEBUF        ; $0200 — Wozmon line accumulation buffer

; RTS water marks.  The same pair the BIOS Kernal uses (BIOS.inc), and for the
; same reason: see the RTS FLOW CONTROL section below.  RTS goes up at
; SC_RTS_HIGH_WATER unread bytes with $40 still spare in the ring, and comes
; down again below SC_RTS_LOW_WATER.  The $40 between them is hysteresis, so a
; line being drained does not flap the pin.
SC_RTS_HIGH_WATER   = $C0                ; Unread bytes at which RTS goes up
SC_RTS_LOW_WATER    = $80                ; Unread bytes below which RTS comes down


; =============================================================================
;   ROM
; =============================================================================

.segment "ROM"
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

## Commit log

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2026-05-11 Production fix
    [Keypad Card.kicad_pcb, Keypad Card.kicad_sch]
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2026-06-21 Silkscreen fix
    [Keypad LCD Helper.kicad_pcb]
2026-07-31 Point the firmware licence at KC Monitor, and update its 6502.inc
    The licence link pointed at Firmware/KIM Controller; the folder is KC Monitor,
    which already had a LICENSE. Its copy of the shared include was still at BIOS
    v1.0, missing disk banking, the addressed load and save routines, and the print
    helpers; it is now identical to the one the other repositories ship. Refreshes the
    software table: WEBULATOR is archived, and the examples, listings, assets and
    tooling repositories were missing.
2026-08-14 Give the KIM its own include, and one ESC gate for both consoles
    Two problems, both from the firmware describing a machine it is not on.
    Build against kim.inc/kim.cfg instead of the ACE's 6502.inc. That file
    documents a fully populated machine with the whole BIOS ROM intact, none
    of which is true here: the Keypad Card overlays $C000-$FFFF and no card
    but the Serial Card is fitted. kim.inc says what the overlay removes,
    defines only hardware the KIM has, and tags every Kernal entry point with
    what it actually does — including that Chrin can never return anything
    once the cart owns IRQ_PTR, and that $0200-$027F and $0400-$04FF are this
    monitor's live buffers rather than the spare RAM 6502.i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
    [6502.cfg, kim.cfg]
2026-09-03 Make serial R a call, so RTS comes back to the prompt
    Wozmon's `R` is `JMP (XAML)`, and this monitor inherited it. The pad's UP
    key has always been a `JSR` (DoUp -> CallUser), so the two consoles
    disagreed about what running a program means: a program ending in RTS came
    home from the pad, and from the terminal left the parser for good.
    The terminal case was worse than a missing prompt. SerProcess reaches the
    run through a chain of tail jumps from `jsr SerService`, so the RTS popped
    MonitorLoop's return address and landed back in the main loop with the
    machine alive but SER_IDX still pointing into the line that launched it.
    The next line typed was appended to "XXXX R" and re-ran the program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
    [KC Monitor.asm]
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2026-10-26 Add the KIM Board Rev 1.0 schematic and its checker
    One through-hole board for the owner's working KIM: the ACE Rev 1.1's
    CPU, RAM, ROM, glue and I/O decode; the Backplane Pro Rev 1.1's 1 MHz
    can, 555 reset and power input; the COB Serial Card on IO5; the Keypad
    Card, Keypad Helper and Keypad LCD Helper; one card slot and the 2x20
    6502 BUS header; and the breadboard headers. One sheet, in the ACE's
    block style.
    What changes from the source boards:
    - The KIM enable jumper (J1) puts KIMB on the Keypad Card's first
    '138 ~E1, with a 10 k pull-up and a BAT85 from HRDB (anode) to KIMB.
    Fitted, the PIA answers $C000-$DFFF and the KC Monitor ROM
    $E000-$FFFF; open, the BIOS ROM answers all of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
2026-10-28 KIM Board Rev 1.0 PCB: placement, 3D models, pin-1 dots, schematic links
    More of the placement, by hand.
    - 3D models: the Cherry MX switches (SW1-SW24) and the ROM's ZIF socket
    (U3) pointed at models KiCad 10 doesn't ship. They now use the ACE's
    CherryMX.step and 228-1277-00-0602J.step, copied into Models, with the
    ACE's offsets: the pads are the same as the ACE's footprints.
    - Pin-1 dots: a 0.8 mm dot on the front silkscreen at pin 1 of every IC
    socket, the ZIF and the oscillator, placed as on the ACE: 2.3 mm past
    pin 1 along the row for a DIP, 6.5 mm beside it for the ZIF, 3.8 mm
    past it for the oscillator. U12's sits beside pin 1, clear of its
    label.
    - Schematic links: U4,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
2026-10-29 KIM Board Rev 1.0: pull the PIA's CB1 and CB2 up through R23
    CB1 and CB2 are unused, and as CMOS inputs they floated. They are now
    joined and held high by one 10k (R23), placed under the LCD. A resistor
    rather than a tie to VCC, because software can make CB2 an output.
    - Schematic: R23 replaces the two no-connects; the PDF is re-exported.
    - PCB: R23 placed, with R15's order fields; the GND pours refilled.
    - Tests/check-schematics.mjs checks that CB1 and CB2 are joined and
    have one 10k pull-up.
    - README: R23 in the keypad and display bullet, and in the checks.
2026-10-31 KIM Board Rev 1.0 PCB: first scripted routing attempt, for reference
    A first full routing, made by a script that searched a grid of each
    part's pin lines: B.Cu horizontal, F.Cu vertical, a via at every turn.
    Everything connects and DRC adds no errors, but the owner judged it
    far from the ACE's routing: too many vias, above all around the BUS
    and CART headers, and lines such as PHI2 forced into detours by lines
    routed before them. Kept here for reference; the next commit takes it
    out again.
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2026-10-31 KIM Board Rev 1.0 PCB: second scripted routing attempt, bus nets only, for reference
    The 35 bus nets alone, each pin-to-pin link tried as a fixed shape
    (straight with 45-degree jogs, an L with one via, a Z with two).
    208 of 235 links routed; the rest were left open. The owner will
    route the board by hand instead. Kept here for reference; the next
    commit takes it out again.
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2026-10-31 KIM Board Rev 1.0: words again for the keypad's LEFT, RIGHT and UP keys
    This reverts commit 416ed65. The owner prefers the words to the arrows,
    so SW1, SW12 and SW21 carry LEFT, RIGHT and UP again, as the KC Monitor
    names them. The schematic PDF goes back with them.
2026-11-02 KIM Board Rev 1.0 PCB: routing finished, DRC clean
    The owner has finished routing the board by hand. A plain DRC now reports
    0 violations, 0 unconnected items and 0 schematic parity issues.
    The project file carries the owner's suppressions: silk_overlap is set to
    ignore, the bottom-left corner hole's courtyard in the breadboards' rule
    area is excluded, and so is the polarity symbol that differs from its
    library copy.
    It also excludes the 67 remaining violations, all against the LCD's
    courtyard: 5 courtyard overlaps and 62 PTH pads, from U8, U10, C1, C4 and
    R23. The owner accepts those parts under the LCD, which stands above them
    on headers and standoffs. Each is excluded by item and positi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
2026-11-02 KIM Board Rev 1.0: centre six vias, complete the BOM, label the KIM jumper
    Six vias sat up to 0.12 mm off the point where their tracks meet, on VCC
    (three), A7, D2 and PA0, with tiny stubs bridging the gap. Each now sits
    where its tracks meet and the seven stubs are gone. The tracks stay
    straight; the short A7 diagonal is about 44 degrees rather than 45. The
    GND pours are refilled, because Fabrication Toolkit exports the saved fill.
    D2, J2, J3, U8, U9, X1 and Y1 were marked exclude from BOM, carried over
    from the older boards, so an exported BOM would have missed them. They are
    on it now, in the schematic and the PCB. JP1, TP1 and TP2 stay excluded.
    Y1's value now reads "1.8432 MHz" rather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
2026-11-02 KIM Board Rev 1.0: 3-pin KIM jumper, production files, images and 3D model
    J1 is now a 3-pin header: pin 1 is KIMB, pin 2 is GND and pin 3 isn't
    connected. A shunt on pins 1 and 2 selects the KIM, and on pins 2 and 3
    it selects BASIC. The silkscreen labels KIM and BASIC with a pair of
    arrows at pin 2, as on KEY2USB, and the schematic's note and PDF follow.
    The README's jumper section says the same.
    The owner moved J1 and R15 up about 1 mm, re-routed the tracks around
    them, moved a resistor's label, and exported the production files, board
    images and STEP model. DRC reports 0 violations, 0 unconnected items and
    0 parity issues, with the saved pours and after a refill. The Gerbers'
    geometry,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
2026-11-02 Production: track the exported CSV files, as the ACE does
    Production/.gitignore skipped *.csv, so each board's bom.csv,
    designators.csv and positions.csv stayed on one machine while its zip and
    netlist.ipc were committed. The rule is gone, and all four boards' CSV
    files are added as they were exported.
2026-11-02 check-schematics: the KIM jumper's KIM and BASIC positions
    J1 is now a 3-pin header, so the checker's words follow it, and it models
    the BASIC position: the shunt on pins 2 and 3, not an open jumper. With
    J1's pin 3 wired to KIMB on a scratch copy, the check fails in the BASIC
    position; on the real board it passes.
    The comments that cited KIM-PLAN.md, a file that's never committed, now
    cite the README's KIM enable jumper table.
2026-11-02 KIM base plate: the KIM Board's hole, the Hanger and a mounting drawing
    One plate now takes either build. Plate.svg, Plate.lbrn2 and Plate.stl gain
    one hole, Ø3.2 at (16, 224), under the KIM Board's bottom-left corner hole,
    and keep all 22 of the old build's holes. The hole is added to the three
    files directly, without the Fusion model, so a new export from Fusion would
    lose it.
    Hanger.stl was missing from CAD/Bases. It is recovered from The KIM.3mf,
    which still holds it.
    Plate Mounting Drawing (SVG and PNG) shows where the boards mount on the
    plate for both builds, every hole's position, how each hole goes together
    and the hardware each build needs. The KIM Board's counts are for its new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
2026-11-03 README: the KIM Board's bill of materials
    Every part with a supplier number where one could be confirmed, in the same
    table as the other boards, and checked against Production/KIM Board/Rev 1.0's
    bom.csv: 109 references, none missing and none extra. A second table lists what
    the schematic doesn't: shunts, sockets, breadboards, keycaps, the power supply
    and the serial cable.
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2026-11-03 KIM Board Rev 1.0: J5's supplier is Digi-Key 732-5401-ND
    J5 carried the Amazon link for a plain female header and no Digi-Key number.
    Only those two fields change, in the schematic and the PCB. The copper,
    silkscreen, mask and outline exports are identical before and after, so the
    boards already ordered still match. ERC reports 0, and DRC with parity reports
    0 violations, 0 unconnected items and 0 parity issues.
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2026-11-03 MM74C922: buy it from Jameco, not Amazon
    The KIM Board's U16 and the Keypad Helper's U1 now point at Jameco's 74C922,
    DIP-18, in the README's BOMs and in the schematics' and the KIM Board PCB's
    supplier fields. Only that field changes. The KIM Board's copper, silkscreen,
    mask and outline exports are identical before and after.
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2026-11-04 Board images: every revision rendered the same way
    Front and back, at 2400 x 1600, on white and with no background, in the black solder
    mask and white silkscreen the boards are made with. They replace images that came from
    two methods, in nine different sizes.
2026-11-05 BOM: one set of part numbers across AC6502
    Writes the shared parts catalogue into every schematic and PCB. Each part now
    has the same Digikey, Mouser, Jameco, LCSC and Other fields. Junk fields imported
    with library parts are gone, and so is MPN, because the Fabrication Toolkit
    falls back to it and put it in bom.csv's LCSC column.
    bom.csv is now an accurate BOM. Only card edges, solder jumpers and test points
    are excluded. A blank LCSC cell means JLCPCB doesn't place the part.
    Where the silk doesn't print it, Value says what to fit: BAT85, R6551AP, 33pF and
    so on. A do-not-fit resistor says so. Made boards whose silk prints an old value
    keep it, and the known issues in BOM.md will cover th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
2026-11-05 BOM.md: every part, by revision, with known issues and cart files
    BOM.md has a parts list for every revision, with Digi-Key, Mouser and other
    sources, how to tell which revision you have, and the known issues that change
    what to buy or fit. BOM/ holds a Digi-Key and a Mouser file for each revision.
    Revisions with soldered parts also have through-hole files that leave them out.
    The README's old BOM tables disagreed with the schematics, so they now link here.
    Revision histories and build notes stay in the README.
    Where the build notes say to fit something else, the lists now order that: 10k
    pull-ups on ACE Board 1.0, CPU Card 1.0, DEV Board 1.0 and Main Board 1.0 and 1.1,
    and no RESB pull-up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
2026-11-05 Everything derived from the boards, brought up to date
    Board images are re-rendered for every revision whose silk or fitted parts
    changed, so they show SERIAL (DTE) and the rest. The revision histories now say
    what changed on the silk, and wording that pointed at the old BOM tables is gone.
    3D model paths that led nowhere are fixed: old KiCad variables, a folder that no
    longer exists, and models KiCad 10 only ships as STEP. Those boards' STEP files
    and images now include all their parts.
    positions.csv no longer lists parts that aren't fitted. Made and ordered boards'
    fabrication exports are unchanged, and so are DRC and schematic parity.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
2026-11-05 BOM: 40- and 32-pin sockets get their part numbers; keyswitch model is blue
    BOM.md and carts: socket rows had no part numbers, because the generator
    looked up the wrong catalogue id.
    CherryMX model: stem is blue, matching MX2A-E1NA in the BOM. Images and
    STEP of the boards using it re-exported.
2026-11-05 Barrel jack: Same Sky PJ-102AH replaces the obsolete DCJ200-10-A-K1-K
    The manufacturer's footprint, rotated 180 degrees, has the same pad
    positions and body as BarrelJack_Horizontal. Only part fields, BOM.md and
    cart files change: Gerbers and drill files are identical. Not yet fitted
    to a board.
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2026-11-05 Library parts named for what they are, not a part number
    Footprints, symbols and 3D models in "6502 Parts" are named for their
    function and shape (RJ45 Jack LED, CR2032 Holder, 6502 Card Slot, Power
    Switch, SID, ACIA 6551, PIA 6521), so a replacement part with the same
    footprint needs no rename. Every repo carries the same copy of each part,
    re-saved by KiCad 10, and each symbol library holds every symbol its
    schematics use. VCS's 65C02 and 65C22 had wrong pin types; ACE's are now
    in all five. Unused DS01C-254-L-08BE and Mini-Black removed.
    Every revision's Gerbers and drill files export the same before and after.
    DRC is unchanged; ERC loses six missing-symbol warnings. Production files
    for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
2026-11-05 BOM: known issue for a silk label that names the wrong part
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2026-11-06 README: shared lines
    A Shared lines section, the same in all five KiCad repos: one 10k pull-up
    on each of RESB, IRQB, NMIB, RDY and BE, on the board with the CPU, and none
    on any other board, so two never sit in parallel. A board's own reset
    circuit pulls RESB low but never carries the pull-up.
2026-11-06 Schematics: bus connectors drawn one way; README: extra pins and HRDB
    Every 6502 bus, cart and card connector on every schematic, made revisions
    included, is drawn one way: a short wire and a global label on each used
    pin, a no-connect flag on each unused one, GND and VCC as global labels,
    and label shapes fixed per signal as the CPU sees it. Bus lines, bus
    entries and local labels for the bus are gone, which clears every "local
    and global labels have same name" ERC warning. Labels match the silk.
    Where bus pins 4 and 6 carry EXP1 and EXP0, or a cartridge grounds them, a
    note on the schematic says what HRDB (High ROM disable bar) does with them.
    The README's new Extra pins section explains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
2026-11-07 Schematics: label shapes follow the signal
    Every global label's shape now shows which way the signal flows at the
    pin it is drawn on: output where it is driven, input where it arrives,
    bidirectional where both, passive for VCC and GND. A bus connector takes
    the board's view: on a board that drives the bus (a CPU board, a
    backplane) the addresses, RWB, SYNC, PHI2 and RESB flow into it and the
    interrupt and control lines come out; on a card a signal flows into the
    edge only if the card drives it (a clock, a reset, an interrupt through
    its diode and jumper) and out of it otherwise.
    The connector redraw had given each label one shape per signal name, so
    address, RWB and PHI2 labels at chip inpu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
2026-11-07 Schematics: keyboard circuit, 74C922 and level shifter labels by signal flow
    The keyboard circuit around the ATmega1284 is labelled as on the ACE
    wherever it appears: the ATmega strobes the matrix on PB and reads PA,
    drives CA1 and CB1 and reads CA2 and CB2; the VIA's port pins and the
    headers carrying its port are bidirectional; a KEYBOARD header takes PB
    in and gives PA out at the encoder, and the reverse at the keyboard's end.
    The 74C922's Y1 and Y2 are inputs: it scans on X and reads on Y.
    VGA Card Pro: INTB_3V3 at Q1's source is an input, from the Pico, which
    drives the interrupt. The check had read Q1's pins in the wrong place.
    No connection changed: each netlist and ERC result is t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
2026-11-07 Schematics: drawn as KiCad draws by default
    - Every GND symbol shows its name, 3.81 mm below it, as KiCad places a new
    one: 128 hid it and most sat at 5.08 mm, an older default. Three moved
    aside by hand stay; one on the DEV Board sits left to clear a label.
    - A global label at 270 degrees is right-justified, as KiCad writes it, so
    the cart GND labels no longer lie over their own tie wire (ROM Cart,
    Flash Cart, Keypad Card).
    - CPU Card 1.0, 1.1 and Main Board 1.0: "Jumper ... for original 6502" is
    text on the sheet, spelled right, not a field on the jumper; the field
    is gone from the schematic and the PCB footprint. The schematic-to-PCB
    check is unchanged and every Gerber layer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
2026-11-07 README, BOM, REVISIONS: which revision to make, and the off-board headers
    Every revision now carries one of three labels, with a one-line reason:
    Tested, Proven design (not built at this revision, but its circuit is a
    tested revision's) or Untested. REVISIONS.md shows it in place of the old
    Tested column, BOM.md beside each revision, and a new README section,
    "Which revision to make", gives each board's newest revision and its label.
    All three are generated from one data file, so they can't disagree.
    A new README section, "Off-board headers", says what the small headers such
    as RESET SW, CLOCK ENBL SW, POWER LED and VCC are for: building a board into
    a case, with the case's parts wired to t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
2026-11-07 CAD: the KIM's plate, mounting drawing and STL, generated from CAD/Assembly.json
    Tools/cad/make.py writes CAD/Bases/Plate.svg, the mounting drawing (SVG and
    PNG) and Plate.stl from the assembly file, the boards' PCBs and the
    standards (CAD.md C4). Against Fusion's plate every hole and the outline
    agree within 0.05 mm, but for the Cable Bridge's two holes, Ø3.4 to Ø3.2:
    the standard M3 clearance, by the owner's ruling (C2 D3). Plate.svg is now
    drawn as the computer is used, not turned 180°. The drawing's hole numbers
    and hardware counts are unchanged, now counted from each hole's kind.
    Plate.lbrn2 needs remaking from the new Plate.svg.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
2026-11-09 Tools/cardedge/: one card edge for every card and cart (KICAD.md K28a) standard.json says it once: the card and cart outlines, placed by the fingers; a cart's four shell holes, each pair centred; no 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
    The library's 6502 Card Edge loses F.Paste and B.Paste, so n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
2026-11-09 Tools/cardedge/: cart holes at 5.0 and 13.0 mm; refilled pours are Proven
    The owner's ruling (KICAD.md K28): a cart's M3 holes go 5.0 mm from the top
    edge and the sides, its M2 holes 13.0 mm from the sides, each pair centred.
    They were 4.849 and 4.95 mm from the sides, a slip in Fusion 360. Proven
    design now covers pours refilled with DRC and the netlist check passing, as
    moving a card's outline refills its pours.
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2026-11-09 Keypad Card 1.1: one card edge (KICAD.md K28b)
    Fixed in place by Tools/cardedge/: no solder mask on the tab, front or
    back, from the fillets' ends down, so the fingers seat and make contact
    better; no paste on the fingers; the outline redrawn to the one card shape
    around the fingers, moved by up to 0.05 mm. No track, pad, via or hole
    moved (gproof.py --no-fill against the last commit); the pours are
    refilled. Label, History and every derived file follow.
    gproof.py: REV@COMMIT reads a revision from git, so a revision fixed in
    place is proven against its last commit, and each differing layer says where
    its differences lie. cardedge.py takes a relative path.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
2026-11-09 Board images: bare FR4 in its own colour, so a card's bare tab shows
    render.py drew the core with no colour, so KiCad showed bare board almost
    as dark as the black mask, and the cards' new mask-free tabs couldn't be
    seen. The core is now FR4 natural, which shows wherever there's no mask: a
    card's tab, and the thin ring where the mask stops short of a pad. Every
    image is rendered again; the masked areas are unchanged.
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2026-11-09 flow.py: a jumper to a rail sets a level; it drives nothing
    The card-edge PHI2 label on the Video Card pointed the wrong way, and
    derived-check passed it. flow.py took any jumper to VCC or GND for a
    source: JP2, which can tie U4's enable to VCC, sits behind JP1 on the
    PHI2 net, so the card seemed to drive PHI2 out to the bus. A jumper to a
    rail is now a pull-up or -down, as a resistor is, whether it ships open or
    bridged; a switch to a rail (a reset button) still drives. The rule in
    KICAD.md K25 is unchanged.
    That flipped both PHI2 labels on every card with a PHI2-enable jumper
    pair, made revisions included: COB RTC Card, VERA Helper and VGA Card
    1.0 and 1.1, VGA Card Pro 1.0, Video Card 1.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
2026-11-11 KIM Board 1.1: U5, the RB/WB gate, is a 74HCT00
    P11 (2026-11-11): an Alliance AS6C62256 with a fast-releasing 74HC00 lot in the gate
    that makes RB and WB misread at 2 MHz; a 74HCT00 there, whose TTL threshold ends the
    strobes a few ns later, cured it in the ACE, reads and writes. Fixed in place: Rev 1.1
    is drawn and never made, and Rev 1.0 keeps its 74HC00. Value and supplier fields only;
    the silk at U5 reads 74HCT00. The parts catalogue gains the 74HCT00 (TI SN74HCT00N,
    SN74HCT00DR), synced to all five repos. Derived files regenerated; the top's outline is
    unchanged.
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2026-11-11 KIM Board 1.1: the ACIA's crystal jumpers
    As on the COB Serial Card and the ACE Board 1.1 (owner, 2026-11-11): R24 (1M) across
    XTLI-XTLO through solder jumper JP2, and C27 (22 pF, SR151A220JAR) from XTLI to
    ground through JP3, both open for the R6551AP. Closed, a Rockwell R65C51P1/P2 (or a
    WDC W65C51) runs; an R65C51P2 on a bare crystal gives no serial at all. The note names
    both parts.
    Routed by the owner: no unconnected items, parity clean; the 67 courtyard errors are
    the ones the board already had, none on the new parts. XTLI passes between C7's pads,
    C7 being VCC/GND decoupling, both quiet, with about 0.3 mm to each pad. check-
    schematics.mjs passes; the top's outline is unchanged. The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
2026-11-13 Silkscreen: no JLCPCB order-number marker on the boards not yet made
    JLCPCB stopped printing order numbers in May 2026, and its help page now asks
    for no JLCJLCJLCJLC text on the silkscreen. The text is removed from the
    Keypad Card 1.1 and Keypad LCD Helper 1.1 (the Keypad Helper 1.1's went with
    its revision); Gerbers prove only F_Silkscreen changed. Made revisions keep
    theirs, which JLCPCB ignores.
    Tools: audit.py fails on the marker on a revision not made or ordered,
    table.py shows it in CONSISTENCY.md's Names on silk, and newrev.py drops it
    when it copies a made revision. Synced from 6502-COB.
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

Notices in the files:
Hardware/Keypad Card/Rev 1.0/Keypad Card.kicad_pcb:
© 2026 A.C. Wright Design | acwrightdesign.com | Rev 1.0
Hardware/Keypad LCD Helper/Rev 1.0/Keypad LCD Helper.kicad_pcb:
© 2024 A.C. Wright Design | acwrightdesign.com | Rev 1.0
